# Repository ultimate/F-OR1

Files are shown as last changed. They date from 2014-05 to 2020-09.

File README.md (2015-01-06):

#F-OR1

Bei der *Formula-OR1* (kurz: *F-OR1*) geht es darum das eigene Können in Bezug auf das Fahren und Bauen eines eigenen Modellautos unter beweis zu stellen. Ziel ist es dabei auf Basis einer vereinheitlichten Grundauswahl an Komponenten ein eigenes Fahrzeug zu entwickeln, zu bauen und sicher durch die Rennen zu steuern.

## Alle Infos auf einen Blick

* **[Reglement](Reglement.md)**
  * **[Anhang A](Reglement - Anhang A.md)**
  * **[Anhang B](Reglement - Anhang B.md)**
* **Gesamt-Wertung**
  * **[Ewige Tabelle](Ranking-1.md)**
  * **[Best-of-3](Ranking-2.md)**
* **Challenges**
  * **[2015-01-09](Challenges/2015-01-09.md)**
  * **[2014-09-26](Challenges/2014-09-26.md)**
  * **[2014-07-18](Challenges/2014-07-18.md)**
  * **[2014-03-21](Challenges/2014-03-21.md)**

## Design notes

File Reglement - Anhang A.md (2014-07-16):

#Reglement - Anhang A

Dieser Anhang enthält Daten und Beschreibungen, sowie ggf. Referenzdokumente für die nach dem Reglement festgelegten Fahrzeugkomponenten & -eigenschaften

Referenz: [Zum Hauptdokument](Reglement.md)

##I. Allgemeines
1. Der maximale Gesamtpreis für Zukaufteile darf die Summe von 50 € pro Teilnehmer nicht überschreiten.
2. Die Fertigung von Teilen per 3D-Druck ist so weit wie möglich auf FDM-3D-Drucker zu beschränken. Die Verwendung des „Objet 30 pro“ 3D-Druckers ist nur für Kleinteile zulässig (z. B. Zahnräder)
3. Fast alle vorgegebenen Grundkomponenten wurden im CAD nachmodelliert und stehen unter [Komponenten](Komponenten) als SolidWorks-Teil/Baugruppe oder STEP zur Verfügung.

##II. Mechanik
1. Allgemeines
  1. Die Prüfung der äußeren Abmaße von kleiner 290 x 215 x 87 mm wird durch die *F-OR1-Normbox* („SpacePilot Pro“-Box) vorgenommen.
  2. Das Fahrzeug muss bei geschlossenem Deckel vollständig, gewaltfrei und in genau dem Zustand in die Box passen, in dem es an der Challenge teilnimmt.
2. Freigaben:
  1. Keine Material- oder Fertigungsbeschränkungen (ausgenommen 3D-Druck, siehe oben)
  2. Äußere Modifikation bestimmter Elektronik-Komponenten (s.u.)
3. Verbote:
  1. Keine weiteren Beschränkungen

##III. Motor & Elektronik
1. Allgemeines
  1. Es werden die folgenden Grundkomponenten vorgeschrieben:
<table><tbody><tr><th>Komponente</th><th>Bezeichnung</th><th>Links</th></tr>
<tr><td>Motor</td><td>B20-30-24S-FIN Brushless Inrunner Motor 3860kv</td><td>[Datenblatt](Datenblätter/Brushless Motor B20-30-24S-FIN - Datenblatt.pdf)<br>[Hobbyking](http://hobbyking.com/hobbyking/store/__24930__B20_30_24S_FIN_Brushless_Inrunner_Motor_3860kv.html)</td></tr>
<tr><td>Motorregler</td><td>Hobby King X-Car 60A Brushless Car ESC</td><td>[Datenblatt](Datenblätter/Hobby King X-Car Motorregler - Datenblatt.pdf)<br>[Manual](Datenblätter/Hobby King X-Car Motorregler - User Manual.pdf)<br>[Software](Datenblätter/Hobby King X-Car Motorregler - USB Programming Software.zip)<br>[(Screenshot)](Datenblätter/Hobby King X-Car Motorregler - USB Programming Software.jpg)<br>[Hobbyking](http://hobbyking.com/hobbyking/store/uh_viewItem.asp?idProduct=28375)</td></tr>
<tr><td>~~Motorregler (alt)~~</td><td>~~Turnigy Multistar 10 Amp Multi-rotor Brushless ESC 2-3S~~</td><td>~~[Datenblatt](Datenblätter/Turnigy Motorregler - Datenblatt.pdf)<br>[Manual](Datenblätter/Turnigy Motorregler - Manual.pdf)<br>[Hobbyking](http://hobbyking.com/hobbyking/store/__25362__Turnigy_Multistar_10_Amp_Multi_rotor_Brushless_ESC_2_3S.html)~~</td></tr>
<tr><td>Akku</td><td>Rhino 1050mah 2S 7.4v 20C Lipoly Pack</td><td>[Datenblatt](Datenblätter/Rhino Lipoly Pack 1050 - Datenblatt.pdf)<br>[Hobbyking](http://hobbyking.com/hobbyking/store/__7307__Rhino_1050mah_2S_7_4v_20C_Lipoly_Pack.html)</td></tr>
<tr><td>Lenkservo</td><td>HK15138 Standard Analog Servo 38g / 4.3kg / 0.17s</td><td>[Datenblatt](Datenblätter/Servo HK15138 - Datenblatt.pdf)<br>[Hobbyking](http://hobbyking.com/hobbyking/store/__16269__HK15138_Standard_Analog_Servo_38g_4_3kg_0_17s.html)</td></tr>
</table>
2. Freigaben:
  1. Beliebige Wahl von Kabeln und Steckern
  2. Äußere Modifikation des Servos (Gehäuse), ohne Veränderungen der Funktionalität oder des Bewegungsbereichs
  3. Äußere Modifikation der Fernbedienung (Gehäuse), ohne Veränderungen der Funktionalität
  4. Austausch der AA-Batterien durch einen Lipo-Akku inkl. der dafür erforderlichen Anpassung des Gehäuses und der Anschlusskabel.
  5. Der Lüfter des Motorreglers darf entfernt und/oder für andere Zwecke verwendet werden (z.B. zum Kühlen des Motors). Bei Bedarf darf dafür auch das Kabel verlängert werden.
3. Verbote:
  1. Sämtliche zusätzliche elektronische Komponenten
  2. Sämtliche sonstige Modifikationen der vorgeschriebenen Komponenten (z.B. elektronisch/funktional), die über die oben genannten Freigaben hinausgehen.
  3. Weitere Energiequellen (z. B. Solarzellen, Kondensatoren, Energierückgewinnung, etc.)

##IV. Steuerung & Software
1. Allgemeines
  1. Aus folgenden Grundkomponenten kann gewählt werden:
<table><tbody><tr><th>Komponente</th><th>Bezeichnung</th><th>Links</th></tr>
<tr><td>Pistole</td><td>Hobby King GT-2 2.4Ghz 2Ch Tx & Rx</td><td>[Datenblatt](Datenblätter/Hobby King GT-2 - Datenblatt.pdf)<br>[Manual](Datenblätter/Hobby King GT-2 - Manual.pdf)<br>[Control Panel](Datenblätter/Hobby King GT-2 - Control Panel.jpg)<br>[Hobbyking](http://hobbyking.com/hobbyking/store/__10608__Hobby_King_GT_2_2_4Ghz_2Ch_Tx_Rx.html)</td></tr>
<tr><td>Knüppel</td><td>Hobby King 2.4Ghz 4Ch Tx & Rx V2 (Mode 1)</td><td>[Datenblatt](Datenblätter/Hobby King TR6A - Datenblatt.pdf)<br>[Hobbyking](http://www.hobbyking.com/hobbyking/store/uh_viewItem.asp?idProduct=8337)</td></tr>
</table>
2. Freigaben:
  1. Keine weiteren Freigaben
3. Verbote:
  1. Sämtliche zusätzliche Steuerungs- Software- oder Sensorik-Komponenten
  2. Modifikationen der vorgeschriebenen Komponenten

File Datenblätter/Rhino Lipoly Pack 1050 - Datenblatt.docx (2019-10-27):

# Datenblatt Rhino Lipoly Pack 1050

Bezeichnung | Rhino 1050mah 2S 7.4v 20C Lipoly Pack
Link | http://hobbyking.com/hobbyking/store/__7307__Rhino_1050mah_2S_7_4v_20C_Lipoly_Pack.html

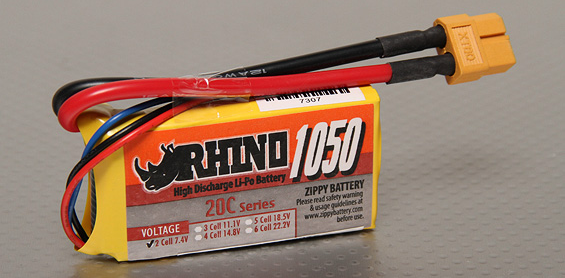
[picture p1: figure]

Bild
Elektrische Eigenschaften | Capacity 1050mAh Constant discharge 20C Burst rate 30C (15sec) Configuration 2S 7.4v Discharge plug XT60 Max Charge Rate 2C

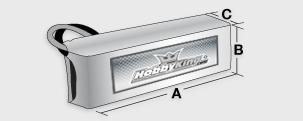
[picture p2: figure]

Mechanische Eigenschaften | Weight (g) 71 Length-A (mm) 70 Height-B (mm) 35 Width-C (mm) 11

F-OR1 Datenblatt Stand: 13.12.2013

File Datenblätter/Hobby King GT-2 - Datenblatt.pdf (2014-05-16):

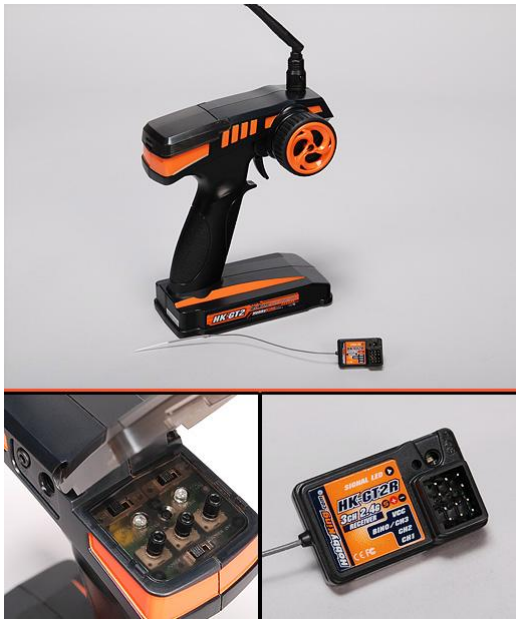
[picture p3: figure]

F-OR1 | Datenblatt | Stand: 13.12.2013

# Datenblatt Hobby King GT-2

Bezeichnung | Hobby King GT-2 2.4Ghz 2Ch Tx & Rx
Link | http://hobbyking.com/hobbyking/store/__10608__Hobby_King_GT_2_2_4Ghz_2Ch_T x_Rx.html (http://hobbyking.com/hobbyking/store/__10608__Hobby_King_GT_2_2_4Ghz_2Ch_Tx_Rx.html)

Bild

Sender | Model | Car/Boat
Channels | 2ch
RF power | Less than 20dbm
Modulation | GFSK
Code type | Digital
Sensitivity | 1024
Low voltage warning | Yes (less than 9V)
DSC port | Yes (3.5mm)
Charge port | Yes
Power | 12VDC (1.5AA x 8)

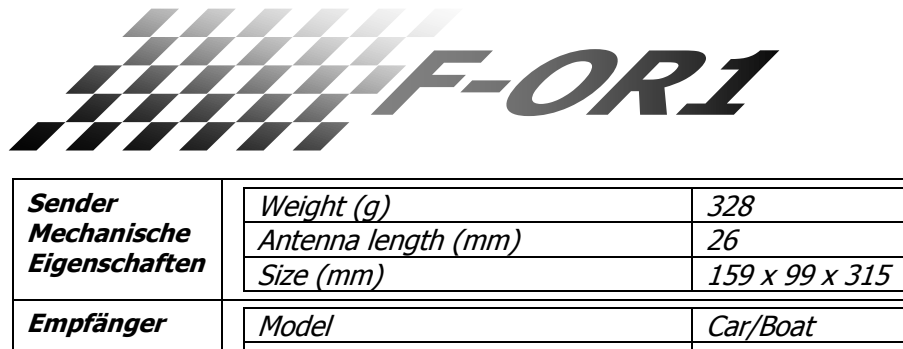
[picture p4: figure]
Sender Mechanische Eigenschaften; Weight (g); Antenna length (mm); Size (mm); Empfänger; Model; Car/Boat

F-OR1 | Datenblatt | Stand: 13.12.2013
Channels | 3ch
Frequency band | 2.4Ghz
Modulation | GFSK
Sensitivity | 1024
RF. receiver sensitivity | -100dbm
Power | 4.5~6VDC

Empfänger
Mechanische
Eigenschaften
Weight (g) | 5
Antenna length (mm) | 26
Size (mm) | 37.6 x 22.3 x 13

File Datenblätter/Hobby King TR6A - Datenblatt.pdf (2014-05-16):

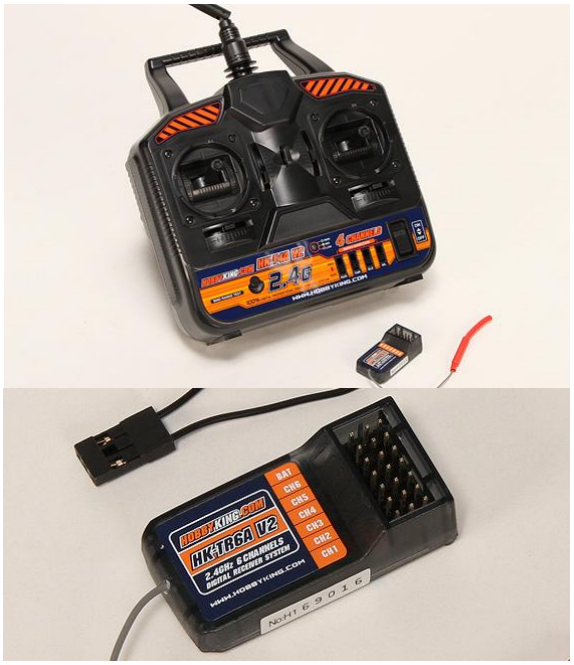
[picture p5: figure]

F-OR1 | Datenblatt | Stand: 13.12.2013

# Datenblatt Hobby King TR6A

Bezeichnung | Hobby King 2.4Ghz 4Ch Tx & Rx V2 (Mode 1)
Link | http://www.hobbyking.com/hobbyking/store/uh_viewItem.asp?idProduct=8337

Bild

Sender

Model | Universal
Mode | 1 (Throttle on the right)
Channels | 4ch
Power | 12VDC (1.5AA x 8) ?

Sender
Mechanische
Eigenschaften
Weight (g) | 989 (Package)
Antenna length (mm) | ?
Size (mm) | ?
Empfänger | Model | Car/Boat
Channels | 6ch
Frequency band | 2.4Ghz
Power | 4.5~6VDC ?

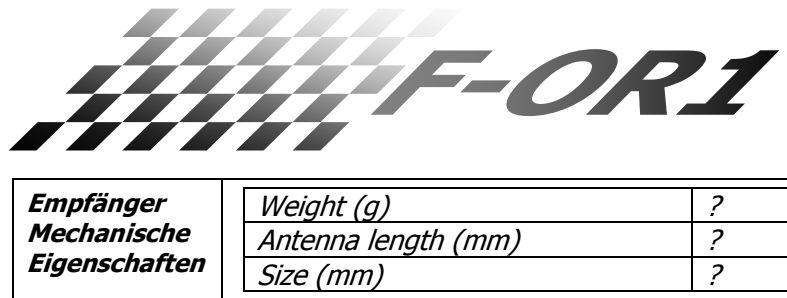
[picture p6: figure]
Empfänger Mechanische Eigenschaften; Weight (g); Antenna length (mm); Size (mm)

F-OR1 | Datenblatt | Stand: 13.12.2013

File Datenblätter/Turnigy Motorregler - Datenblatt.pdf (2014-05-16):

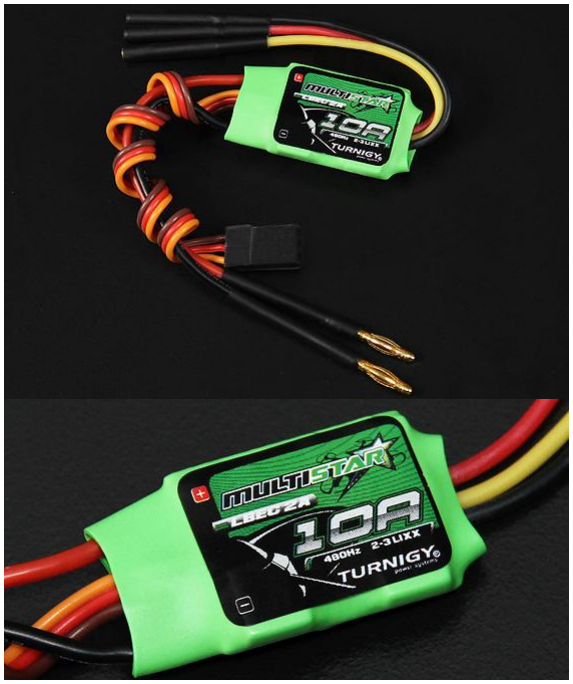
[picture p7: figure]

F-OR1 | Datenblatt | Stand: 13.12.2013

# Datenblatt Turnigy Motorregler

Bezeichnung | Turnigy Multistar 10 Amp Multi-rotor Brushless ESC 2-3S
Link | http://hobbyking.com/hobbyking/store/__25362__Turnigy_Multistar_10_Amp_Multi_ rotor_Brushless_ESC_2_3S.html (http://hobbyking.com/hobbyking/store/__25362__Turnigy_Multistar_10_Amp_Multi_rotor_Brushless_ESC_2_3S.html)

Bild

Elektrische Eigenschaften
Constant Current | 10A
Input Voltage | 2-3 cell Lipoly
BEC | Yes (linear) [Remove middle wire to dissable]
BEC Output | 5V/2A
PWM | 8 KHz
Max RPM | 240,000rpm for 2 Pole Brushless Motor
Discharge Plugs | Male 3.5mm Bullet Connector
Motor Plugs | Female 3.5mm Bullet Connector

Mechanische Eigenschaften
PCB Size (mm x mm) | 22 x 17
Weight (g) | 16

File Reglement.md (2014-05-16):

# Reglement
##I. Organisation
1. Organisation und Leitung der *F-OR1* übernimmt das *F-OR1-Komitee* bestehend aus Marco und Julian.
2. Das *F-OR1-Komitee* behält sich jederzeit Änderungen vor. Änderungen werden mit rechtzeitiger Ankündigung und Wirkung zur übernächsten Challenge bekannt gegeben. Änderungen können mit Einverständnis aller Teilnehmer auch kurzfristig in Kraft gesetzt werden.

##II. Grundlegendes
1. Der Spaßt steht im Vordergrund!
2. Der Zeitaufwand während der Arbeitszeit ist auf einen ange-messenen Zeitrahmen zu begrenzen.
3. Fertigungs- und Material-Kosten sind so gering wie möglich zu halten (siehe auch [Anhang A](Reglement - Anhang A.md)).
4. In diesem Repository werden alle allgemeingültigen Information gesammelt und veröffentlicht. Dazu gehören z. B. das Reglement, Rennergebnisse, Datenblätter, etc.

##III. Durchführung
1. Das Können der Fahrer und der Fahrzeuge wird in regelmäßigen Challenges ermittelt deren Termin unter allen Teilnehmern abgestimmt wird.<br/>Ziel ist es die Challenges ungefähr im Abstand von 2-3 Monaten auszutragen. 
2. Die Challenges werden als **Team-Events an einem Freitag nach der Arbeit im "Labor"** oder an einem anderen verabredeten Ort ausgetragen.
3. Längeren Challenges können alternativ auch als Rennwoche durchgeführt werden. In diesem Fall hat innerhalb der festgelegten Rennwoche jeder Teilnehmer die Möglichkeit die Challenge beliebig oft zu absolvieren um eine Wertung zu erlangen. Absolvieren der Challenge, sowie die Wertung muss dabei von mind. einem anderen Teilnehmer beobachtet und bestätigt werden.
4. Sofern es die Art der Challenge zulässt ist bei Urlaub oder Krankheit ein Ausweichtermin für das Erlangen der Wertung auch außerhalb des Team-Events oder der Rennwoche für den betroffenen Teilnehmer möglich. Die Festlegung des Ersatz-Termins erfolgt in Absprache mit dem *F-OR1-Komitee*. Der Ersatztermin ist möglichst zeitnah zum eigentlichen Termin der Challenge anzusetzen. Nach Möglichkeit sind Urlaube jedoch schon bei der Festlegung des Challenge-Termins zu berücksichtigen.
5. Der Teilnehmer, der bei der aktuellen Challenge am **schlechtesten** abschneidet, legt die Aufgabe/den Inhalt der nächsten Challenge und damit auch die Ausführungsvariante der Challenge fest. Sollte ein Teilnehmer zweimal in Folge die Wahl der nächsten Aufgabe zugesprochen bekommen, so fällt die Festlegung der Aufgabe/des Inhalts der nächsten Challenge auf den nächstbesseren Teilnehmer.<br/>Vorschläge für mögliche Challenges können [Anhang B](Reglement - Anhang B.md) entnommen werden.
6. Testfahrten können auch jederzeit auch außerhalb des Team-Events bzw. der Rennwoche beliebig oft durchgeführt werden, werden jedoch nicht in die Wertung genommen.
7. Die Festlegung des Termins und der Art der nächsten Challenge hat möglichst zeitnah nach Abschluss der aktuellen Challenge zu erfolgen und ist jedoch **mind. 14 Tage im Voraus** anzukündigen.
8. Für jede Challenge ist ein **eindeutiges, messbares Wertungskriterium** festzulegen, welches zusammen mit der Festlegung der Art der Challenge bekannt gegeben wird.<br/>Bei der Wahl einer mehrstufigen Wertung (siehe [Anhang B](Reglement - Anhang B.md)) ist darüber hinaus ein entsprechender Zeit- oder Ablaufplan zu veröffentlichen.
9. Hinzukommende oder ausscheidende Teilnehmer müssen ihr hinzukommen bzw. ausscheiden bis spätestens 14 Tage vor der nächsten Challenge bekannt geben.

##IV. Teilnahmebestimmungen
1. Teilnehmen kann jeder, der mit seinem Fahrzeug die nachfolgenden Bestimmungen einhält.
2. Für die Beschreibung der Fahrzeuge werden die **Eigenschaften nach 3 Kategorien** unterschieden:
    1. **Mechanik** - Beinhaltet die tragende Konstruktion wie z. B. Fahrgestell und Karosserie sowie Aufhängung, Räder, Antriebs- und Lenkmechnik und Verbindungselemente
    2. **Motor & Elektronik** – Beinhaltet den Motor, sowie sämtliche elektronischen Bauteile die für die elektrische Versorgung des Fahrzeugs oder den Betriebs des Motors erforderlich sind (ausgenommen Steuerungskompo-nenten, siehe c.), sowie Kabel und Stecker
    3. **Steuerung & Software** – Beinhaltet sämtliche Komponenten, die für die Steuerung des Fahrzeugs erforderlich sind, inkl. ggf. dazugehöriger Sen-sorik (einschließlich Fernsteuerung etc.)
Bei nicht eindeutiger Zuordbarkeit der Komponenten zu einer Kategorie entscheidet das *F-OR1-Komitee* über die Zuordnung.
3. Für alle Fahrzeuge wird die in [Anhang A](Reglement - Anhang A.md) beschriebene Grundkonfiguration an festgelegten Komponenten & Eigenschaften vorgeschrieben. Alle Komponenten sind im unmodifizierten Originalzustand zu verwenden. Veränderungen oder Manipulationen der Komponenten sind nur nach vorheriger Freigabe durch das Reglement zulässig.
4. Nach Abschluss einer Challenge, dürfen bis zum Abschluss der nächsten Challenge dürfen ausschließlich Modifikationen innerhalb **einer Kategorie** vorgenommen werden.<br/>Der Stand des Fahrzeugs wird für jede Challenge fotografisch sowie falls erforderlich anderweitig dokumentiert (z. B. Schalt-plan, Code, etc., siehe nachfolgend Fahrzeugeigenschaften)
5. Das Wechseln und/oder Nachladen des Akkus ist innerhalb einer Wertung (siehe V) nicht gestattet. Eine Ausnahme stellen mehrstufige Challenges dar, sofern das Wechseln und/oder Nachladen im Ablauf beschrieben ist.

##V. Challenge-Wertung
1. Die Wertung der Challenges erfolgt durch Punktvergabe anhand des zuvor festgelegten Wertungskriteriums in der folgenden Punktefolge und wird an die tatsächliche Teilnehmerzahl n der Challenge angepasst:<br><table><tbody><tr><th>Platz</th><th>1</th><th>2</th><th>3</th><th>...</th><th>n-2</th><th>n-1</th><th>n</th></tr><tr><td>Punkte</td><td>n-1</td><td>n-3</td><td>n-4</td><td>...</td><td>1</td><td>0</td><td>0</td></tr></table><br>Bei Wertungsgleichheit mehrerer Teilnehmer m erhalten diese die gleiche Punktzahl entsprechend des besseren Platzes. Die nachfolgenden m-1 Plätze werden ausgesetzt.
2. Über die Punktwertung hinaus werden Bonus- oder Strafpunkte wie folgt vergeben bzw. abgezogen:<br><table><tbody><tr><th>Kriterium</th><th>Punkte</th></tr><tr><td>Nicht-Teilnahme an der Challenge</td><td>- 2</td></tr><tr><td>Keine Modifikation des Fahrzeugs seit der letzten Challenge</td><td>+ 2</td></tr><tr><td>Design-Bonus</td><td>+ 1</td></tr></table><br>Anmerkungen:
    1. Die Nicht-Teilnahme an der Challenge bedeutet den Ausschluss bei der Vergabe der Bonus-Punkte.
    2. Sofern die Art der Challenge eine Urlaubs oder Krankheitsregelung nach II/4 nicht zulässt, werden keine Strafpunkte für die Nicht-Teilnahme abgezogen.
    3. Der Design-Bonus wird durch demokratische Wahl der Teilnehmer vergeben und belohnt das optisch ansprechendste Fahrzeug. Er wird bei jeder Challenge neu vergeben.

##VI. Gesamt-Wertung
1. Die Ergebnisse der Team-Events bzw. Rennwochen in Form der Challenge-Wertung fließen in die Gesamtwertung ein.
2. Die Gesamtwertung ist untergliedert in mehrere Rankings:
    1. **Ewige-Tabelle**<br>Die **Punktzahlen aller Challenge-Wertungen** inkl. Bonus-/Strafpunkte werden je Teilnehmer addiert. Bei Punktgleichheit führt der Spieler, der ohne Berücksichtigung von Bonus-/Strafpunkten mehr Punkte hat.
    2. **Best-of-3**<br>Die **Punktzahlen der letzten 3 Challenge-Wertungen** exkl. Bonus-/Strafpunkte werden je Teilnehmer addiert.
3. Die Rankings werden von Julian gepflegt und hier auf github veröffentlicht:
    1. **[Ewige-Tabelle](Ranking-1.md)**
    2. **[Best-of-3](Ranking-2.md)**

##VII. Anhänge
* **[Anhang A](Reglement - Anhang A.md)** (Technische Vorgaben)
* **[Anhang B](Reglement - Anhang B.md)** (Challenge-Vorschläge)

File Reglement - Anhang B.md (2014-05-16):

#Reglement - Anhang B

Dieser Anhang enthält Vorschläge und Kurzbeschreibungen möglicher Challenges.

Referenz: [Zum Hauptdokument](Reglement.md)

##I. Vorschläge für mögliche einstufige Challenges
1.	Beste Rundenzeit(en) (Wertung über 1-n beste Runden)
2.	Topspeed oder Topbeschleunigung
3.	Kleinste Zeit für X Runden
4.	Meistgefahrene Runden pro Zeit
5.	Ausdauer (Meiste Runden mit 1 Akkuladung, Durchführung auf sehr einfacher Strecke wie „Oval“ oder „Acht“)
6.	Geschicklichkeitsübung (Hindernissparcour, Slalom, Weit-sprung, …)
7.	Fahrzeug-Fahrer-Kombi-Spring (Fahrer & Fahrzeug müssen Strecke gleichzeitig absolvieren)
8.	Dragster
9.	Fußball
10.	Crash-Derby

##II.	Vorschläge für mögliche mehrstufige Challenges
1.	K.O.-Meisterschaft (bestehend aus einer der obigen Challenges)
2.	Gruppen-Rennen
3.	Jeder-Gegen-Jeden (Mini-Liga)

##III. Richtwerte für die Auswahl der Challenges
1.	Eine Wertung muss mit 1 Akkuladung erzielt werden können.

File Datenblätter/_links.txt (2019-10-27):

http://www.hobbyking.com/hobbyking/store/RC_PRODUCT_SEARCH.asp?strSearch=bone
http://www.hobbyking.com/hobbyking/store/__49322__S3M_153_Belt_The_Devil_1_10_4WD_Drift_Car.html
http://www.hobbyking.com/hobbyking/store/__49321__S3M_174_Belt_The_Devil_1_10_4WD_Drift_Car.html
http://www.hobbyking.com/hobbyking/store/__52069__RJX_X_treme_50_EP_Aluminum_Front_Belt_Pulley_S3M_16T_XT90_60007.html
http://www.hobbyking.com/hobbyking/store/__52099__RJX_X_TRON_500_Tail_Belt_Pulley_16T_with_Pin.html
http://www.hobbyking.com/hobbyking/store/__41357__Alu_15T_Pulley_1_10_Hobbyking_Mission_D_4WD.html
http://www.hobbyking.com/hobbyking/store/RC_PRODUCT_SEARCH.asp?strSearch=pulley
http://www.hobbyking.com/hobbyking/store/__36452__Ball_Diff_Set_1_10_Hobbyking_Mission_D_4WD_GTR_Drift_Car.html
http://www.kugellager-express.de/Kugellager/Miniatur-Kugellager/Miniatur-Kugellager-6--/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

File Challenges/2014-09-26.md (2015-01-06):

#Challenge 2014-09-26

##Beschreibung

Challenge festgelegt durch: **Julian**

###Vorwort
Ihr seid sicher alle gespannt, was ich mir für die nächste Challenge ausdenke – aber es muss noch ein paar Tage in meinem Kopf reifen...
Nur so viel sei schon mal verraten: Sie soll draußen stattfinden! Damit das auch mit dem Wetter noch was wird, der Abstand zur letzten Challenge aber weder zu klein noch zu groß wird, dachte ich wir streben so Ende September an...<br>

Nun zur Challenge an sich: (Sorry, dass es so lang geworden ist... :-/ )

###Ort / Strecke:
* ich schlage vor, dass wir die Challenge [hier (grüner Pfeil)](https://maps.google.de/maps?q=52.524479,13.318796) stattfinden lassen.
* Genau dort wo der Pfeil ist, ist eine kleine Anhöhe, von der man die gesamte Strecke gut im Blick hat (siehe rechts; sollten die Büsche an der West-Ecke stören, können wir die Strecke auch über die Wiese führen – vorausgesetzt dort befinden sich keine Tretminen...)
* da wir damit abseits des Labors sind, sind natürlich auch nicht-h2o-Gäste herzlich eingeladen...

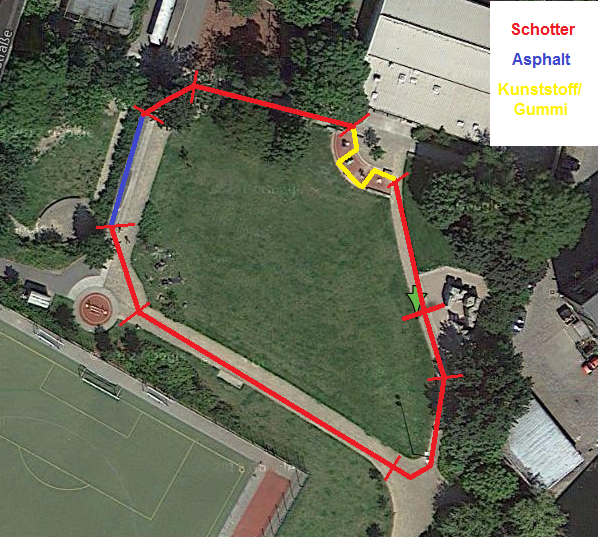
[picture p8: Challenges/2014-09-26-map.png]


*Anmerkung*
* sollte das mit dem Schotter der totale Reinfall sein, so verlegen wir die Challenge auf das Dach des Labors, wo wir einen ähnlichen Streckenverlauf absperren...

###Rennen (ohne Festlegung der Reihenfolge)
1. KO-Rennen (mit Betonung auf "Rennen"; zum Warm werden ;-) ):
  * 1 Runde auf Zeit, alle einzeln nacheinander
  * Auto & Fahrer müssen die Strecke gemeinsam passieren (gelbe Schikane für Fahrer ausgenommen)
  * Start von Auto & Fahrer gleichzeitig, Zeit wird gestoppt, wenn beide (Auto & Fahrer) Ziellinie passiert haben
  * optional: jeder hat 3 Versuche, der beste Versuch zählt – ob die 3 Versuche wahrgenommen werden, kann jeder für sich entscheiden...
  * die Fahrt-Richtung kann (je Versuch) frei gewählt werden
2. KO-Rennen (mit Betonung auf "KO")
  * 5 Runden alle zusammen
  * ab da scheidet jede Runde der letzte aus (also bei 5 Teilnehmern am Ende der 5., 6., 7., 8. Runde; bei 6 entsprechend mehr)
3. Normales Rennen
  * 8 Runden ganz normale, alle zusammen
4. wie 2, nur anders herum
5. wie 3, nur anders herum

###Punktevergabe:
-	Für die Ermittlung des Challenge-Siegers gilt für alle Rennen die gleiche Punktverteilung (Teilnehmerzahl n):<br>
                1. Platz: n-1 Punkte<br>
                2. Platz: n-3 Punkte<br>
                3. Platz: n-4 Punkte<br>
                n-1. Platz: 0 Punkte<br>
                n. Platz: 0 Punkte<br>
                Nicht-Erreichen des Ziels: -1 Punkte (gilt nicht für Rennen 2 & 4 & Mehrfachversuche bei Rennen 1)

###Sonderregeln:
* Während aller Rennen ist das Anfassen der Autos nicht verboten – ist aber an folgende Bedingungen geknüpft:
  * Die Strecke ist in 8 Abschnitte geteilt (siehe Karte: 3 Geraden, 3 Kurven, 1 Schikane, 1 Bodenwell)
  * Das Auto muss nach dem Anfassen an den Anfang des Abschnitts zurückversetzt 
  * Ich glaub das ist Strafe genug, wenn man bedenkt, dass man dafür ohnehin ganz schön wetzen muss...
* In Ermangelung einer Steckdose ist natürlich das Nachladen (und auch Tauschen) des Akkus verboten.
* Im Reparaturfall benötigtes Werkzeug/Ersatzteile ist natürlich mitzubringen...

##Wertung & Teilnehmer

Teilnehmer    | 1 (Zeit)                           | 1 (Pkt.) | 2 (Pl.) | 2 (Pkt.) | 3 (Pl.) | 3 (Pkt.) | 4 (Pl.) | 4 (Pkt.) | 5 (Pl.) | 5 (Pkt.) | Ges. (Pl.) | Ges. (Pkt.) | Punkte | Boni  
------------- | ---------------------------------- | -------- | ------- | -------- | ------- | -------- | ------- | -------- | ------- | -------- | ---------- | ----------- | ------ | ------     
**Jonas**     | 30.4 s<br>21.6 s<br>**21.1 s**     | 2        | 2       | 2        | 3       | 1        | 1       | 4        | 1       | 4        | 1          | 13          | 4      |   
**Marco**     | **24.7 s**<br>ausgesetzt<br>27.1 s | 1        | 1       | 4        | 1       | 4        | 2       | 2        | 2       | 2        | 2          | 13          | 2      |            
**Chang-Hae** | 25.3 s<br>23.2 s<br>**21.0 s**     | 4        | 4       | 0        | 2       | 2        | 3       | 1        | 3       | 1        | 3          | 8           | 1      | + 1 (keine Modifikation)
**Martin**    | 38.6 s<br>ausgesetzt<br>**31.4 s** | 0        | 3       | 1        | -       | -1       | -       | -        | -       | -1       | 4          | -1          | 0      |        
**Julian**    | 44.7 s<br>**39.3 s**<br>42.1 s     | 0        | 5       | 0        | -       | -1       | 4       | 0        | -       | -1       | 5          | -2          | 0      | + 1 (Design)               

##Rückblick
* Streckenänderung
  * Da es dann doch etwas nass war für die Schotterstrecke haben wir uns dafür entschlossen das Rennen doch wieder auf dem Hof stattfinden zu lassen. Der Streckenverlauf und Rennen wurde dabei aber beibehalten.
* Rennen 1
  * Das KO-**Rennen** war so spaßig wie erwartet. Sowohl für die rennenden, als auch für die Zuschauer :-)
  * Die Startreihenfolge wurde entsprechend der Platzierung des ersten Rennens gewählt. Also: Marco, Chang-Hae, Martin, Jonas, Julian
  * Jonas Wagen verliert in der Schikane ein Vorderrad. Das hindert es aber nicht daran trotzdem ins Ziel zukommen.
  * Marco traut sich nach seinem ersten guten Lauf sogar eine Runde auszusetzen.
  * Martins Wagen verliert im ersten Versuch "nur" den Spoiler. Den zweiten Versuch muss er aber abbrechen, weil er ein Hinterrad verliert...
  * Am Ende entscheidet nur 1/10 Sekunde zwischen Chang-Hae und Jonas
* Rennen 2
  * Marco entscheidet das Rennen knapp für sich...
* Rennen 3
  * Julians Akku ist bereits nach 2 Rennen durch und das Auto kommt nicht mehr von der Stelle, daher muss er für dieses Rennen aufgeben.
  * Bei Martin zerlegt es die gedruckten Teile im Getriebe, womit er leider für alle weiteren Rennen ausfällt...
* Rennen 4
  * Nach einem Akku-Wechsel ist Julian wieder dabei. Das ändert aber nichts daran, dass er Probleme hat mit dem Geradeausfahren...
  * Zudem bricht bei Julian die Motorwelle. Da war die Spannung durch den Riemen wohl etwas groß. Damit ist auch für ihn für heute Schluss...
  * Diesmal lässt Jonas Marco knapp hinter sich.
* Rennen 5
  * Mit drei verbliebenen Fahrern geht es ins dritte Rennen.
  * Die Ausgangssituation ist denkbar spannend. Fast alles ist noch möglich
* Stechen
  * Nach dem 5. Rennen sind Marco und Jonas gleich auf. Der Sieger wird durch ein Stechen ermittelt.
  * Dabei müssen beide gleichzeitig mit ihrem Fahrzeug mitrennen.
* Allgemeines
  * Chang-Hae kassiert als Erster den Bonus-Punkt für das Nicht-Modifizieren seines Fahrzeugs seit der letzten Challenge.
  * Der Design-Punkt ging wieder knapp an Julian. Abgestimmt haben dabei auch 4 Zuschauer.

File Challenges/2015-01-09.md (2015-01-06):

#Challenge 2015-01-09

##Beschreibung

Challenge festgelegt durch: **Martin**

###Zum Rennen selbst
Würde es gerne draußen auf dem Platz vor dem Labor stattfinden lasen, die Strecke wieder kurz vorher hergerichtet. Das hatte ja gut funktioniert beim letzten Mal.
Gerade zu dem Datum könnte das Wettertechnisch so ziemlich alles sein. Und genau darum geht es. 
**Ob Regen oder Schnee wir fahren draußen.**

###Zu den Rennen selbst:
1. Normales Rennen 6 runden wer Erster ist, ist halt erster nichts Besonderes.
2. Nun sollten alle die Strecke kennen, also jetzt dann ein kleines Zeitrennen, gefahren werden nacheinander 3 Runden am Stück. Sind also 2 fliegende runden. Startreihenfolge wird nach der Platzierung aus 1. ermittelt  
3. Gefahren wird in beide Richtungen. Diejenigen die vorher eine ungerade Platzierung hatten  fahren diesmal in die andere die anderen behalten ihre Richtung bei. (6 Runden)
4. Wie drittens aber andersrum damit sich keiner beschwert.
5. Als letztes noch etwas damit wir auch was zum reparieren bekommen, Nach dem heiländer Motto es kann nur einen geben. Jeder klebt sich einen Luftballon auf das Dach und befestigt einen stabilen Draht Vorne am Auto. Jetzt wird solange gefahren bis nur noch einer einen ganzen aufgeblasenen Ballon auf dem Dach hat. Es gibt keine Strecke, gefahren werden kann auf dem gesamten Platz. Um die Luftballons werde ich mich kümmern. Ich denke um den Draht kann sich jeder selbst kümmern.

###Punktevergabe
Bei der Punktevergabe bediene ich mich einfach mal bei unserer letzten Challenge.
- Für die Ermittlung des Challenge-Siegers gilt für alle Rennen die gleiche Punktverteilung (Teilnehmerzahl n):<br>
                1. Platz: n-1 Punkte<br>
                2. Platz: n-3 Punkte<br>
                3. Platz: n-4 Punkte<br>
                n-1. Platz: 0 Punkte<br>
                n. Platz: 0 Punkte<br>
                Nicht-Erreichen des Ziels: -1 Punkte (gilt nicht für Rennen 2 & 4 & Mehrfachversuche bei Rennen 1)
- Ausgenommen 5. Es gibt keinen zweiten nur einen ersten und einen Haufen Verlierer. So kann es halt auch nur einen geben der punkte bekommt und zwar 2 an der Zahl. 

###Zu den Luftballons
Julian: Gibt es eine Regel auf welcher Höhe der Ballon sein muss? Gibt es Regeln für den "Draht"?<br>
Martin: Ich hätte gedacht das der Ballon direkt aufs Auto geklebt wird (doppelseitiges Klebeband oder so) und die Autos sind zwar nicht gleich aber doch gleich genug denke ich.  Und zum Draht würde ich zumindest die Wahl was für einen man nimmt freistellen so von wegen Überlegungen zu Steifigkeit gegen Gewicht oder so. und die Höhe der dratspitze würde ich sagen sollten zwischen 130 und 170 mm über Boden passen. 

##Wertung & Teilnehmer

Teilnehmer    | 1 (Pl.) | 1 (Pkt.) | 2 (Zeit) | 2 (Pkt.) | 3 (Pl.) | 3 (Pkt.) | 4 (Pl.) | 4 (Pkt.) | 5 (Zerst. durch) | 5 (Pkt.) | Ges. (Pl.) | Ges. (Pkt.) | Punkte | Boni  
------------- | ------- | -------- | -------- | -------- | ------- | -------- | ------- | -------- | ---------------- | -------- | ---------- | ----------- | ------ | ------
**Marco**     |         |          |          |          |         |          |         |          |                  |          |            |             |        |            
**Chang-Hae** |         |          |          |          |         |          |         |          |                  |          |            |             |        |        
**Martin**    |         |          |          |          |         |          |         |          |                  |          |            |             |        |        
**Jonas**     |         |          |          |          |         |          |         |          |                  |          |            |             |        |        
**Julian**    |         |          |          |          |         |          |         |          |                  |          |            |             |        |            

##Rückblick
* kommt noch

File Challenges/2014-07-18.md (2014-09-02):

#Challenge 2014-07-18

##Beschreibung

Challenge festgelegt durch: **Chang-Hae**<br>
Nachdem die Autos beim letzten Rennen alle reihenweise ausgefallen sind, soll das Thema der nächsten For1 Ausfallsicherheit sein:<br>
Es werden 4 Rennen nach folgendem Ablauf gefahren:

* Erstes Rennen besteht aus 3 Runden in der Halle<br>(1.Platz: 3 Punkte, 2.Platz: 2 Punkte, 3.Platz 1 Punkt, n-ter Platz 0 Punkte, Ziel nicht erreicht/nicht angetreten -3Punkte)
 * 10min Pause
* Zweites Rennen besteht aus 4 Runden in der Halle<br>(1.Platz: 4 Punkte, 2.Platz: 3 Punkte, 3.Platz 2 Punkte, n-ter Platz 0 Punkte, Ziel nicht erreicht/nicht angetreten -4Punkte)
 * 10min Pause
* Drittes Rennen besteht aus 5 Runden in der Halle<br>(1.Platz: 5 Punkte, 2.Platz: 4 Punkte, 3.Platz 3 Punkte, n-ter Platz 0 Punkte, Ziel nicht erreicht/nicht angetreten -5Punkte)
 * 10min Pause
* Viertes Rennen: Wer schafft die meisten Runden (Akku von den Vorrunden darf nicht gewechselt/nachgeladen werden)<br>(1.Platz: 6 Punkte, 2.Platz: 5 Punkte, 3.Platz 4 Punkte)

Die Autos dürfen während der Rennen nicht berührt/repariert werden (müssen also ein Rennen lang halten). Lediglich in den 10min Pausen dürfen die Autos repariert/nachjustiert werden.

##Wertung & Teilnehmer

Teilnehmer    | 1 (Pl.) | 1 (Pkt.) | 2 (Pl.) | 2 (Pkt.) | 3 (Pl.) | 3 (Pkt.) | 4 (Rd.) | 4 (Pkt.) | Ges. (Pl.) | Ges. (Pkt.) | Punkte | Boni  
------------- | ------- | -------- | ------- | -------- | ------- | -------- | ------- | -------- | ---------- | ----------- | ------ | ------
**Marco**     | 1.      | 3        | 1.      | 4        | 1.      | 5        | 6       | 0        | 1.         | 12          | 4      |        
**Chang-Hae** | 2.      | 2        | 2.      | 3        | 4.      | 0        | X+7     | 6        | 2.         | 11          | 2      |         
**Martin**    | 3.      | 1        | 4.      | 0        | 2.      | 4        | X+6     | 5        | 3.         | 10          | 1      |        
**Jonas**     | 4.      | 0        | 3.      | 2        | 3.      | 3        | X+5     | 4        | 4.         | 9           | 0      |        
**Julian**    | -       | -3       | 5.      | 0        | -       | -5       | -       | 0        | 5.         | -8          | 0      | + 1 (Design)      

##Rückblick
* Rennen 1
  * Bei Julian hat's mal wieder das Getriebe zerlegt. Glücklicherweise hatte er ein (gebrauchtes) Ersatzzahnrad, so dass er den Rest des Rennens und die Pause damit verbrachte dieses auszutauschen
* Rennen 2
  * Julian startet verspätet. Das Austauschen des Zahnrads dauerte 2 Minuten länger... Immerhin schafft er es dann ins Ziel.
* Rennen 3
  * Julians Getriebe ist wieder hin. Damit war's das für ihn für diese Challenge...
  * Es bleibt richtig spannend für das 4. Rennen! Chang, Jonas und Martin sind Punktgleich mit 5 Punkten. Nur Marco hat sich mit 12 Punkten abgesetzt. Da es im 4. Rennen keinen Abzug gibt, ist ihm der Sieg der Challenge damit schon sicher...
* Rennen 4
  * In Runde 7 blockiert Marcos Lenkung und er scheidet aus.
  * Chang, Jonas und Martin verzählen sich bei über 20 Runden. Da nur noch der Rundenabstand bekannt ist beginnen wir neu zu zählen (daher X+ in der Tabelle).
  * Jonas muss nach X+5 Runden aufgeben. Bei einem Crash wird sein An-/Aus-Schalter getroffen. Der Schalter bricht ab und bleibt im Zustand "aus" stehen. Das ist wirklich Pech!
  * Martins Akku ist nach X+6 Runden leer. Damit ist er der einzige, der seinen Akku wirklich leer gefahren hat.
  * Chang gewinnt
* Im Anschluss
  * ... drehen alle (bis auf Julian) noch draußen ihre Runden und sind sich einig, dass das viel cooler ist als auf dem rutschigen Hallenboden...
* Allgemeines
  * Birgit war dabei und hat (fast) alles auf Video festgehalten...
  * Der Design-Punkt geht erneut an Julian (immerhin ein kleiner Trostpreis)

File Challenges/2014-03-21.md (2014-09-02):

#Challenge 2014-03-21

##Beschreibung
Challenge festgelegt durch: **Apsrache aller Teilnehmer**<br>
* 2 Serien à 3 Rennen
* Jedes Rennen à 3 Runden
 
##Wertung & Teilnehmer

Teilnehmer    | 1.1 | 1.2 | 1.3 | Serie 1 | 2.1 | 2.2 | 2.3 | Serie 2 | Gesamt  | Punkte | Boni
------------- | --- | --- | --- | ------- | --- | --- | --- | ------- | ------- | ------ | ----
**Chang-Hae** | 2.  | 1.  | 1.  | **1.**  | 1.  | 2.  | 2.  | **1.**  | **1.**  | 2      | 
**Marco**     | 1.  | 2.  | 3.  | **2.**  | 2.  | 3.  | 1.  | **2.**  | **2.**  | 0      |
**Julian**    | 3.  | 3.  | 2.  | **3.**  | 3.  | 1.  | 3.  | **3.**  | **3.**  | 0      | + 1 (Design)

##Rückblick
* Kein einziges Auto ist heil geblieben
* Während der Rennen musten nicht nur die Autos flitzen ;-)
* Der Sprint in die Werkstatt oder zum gedrehten/gecrashten Auto gehörte quasi mit dazu
* Die Motorregler haben wahre Probleme verursacht. Anfahren war Glücksache...
* Leon und Ronald haben sich als Zuschauer köstlich amüsiert :-)

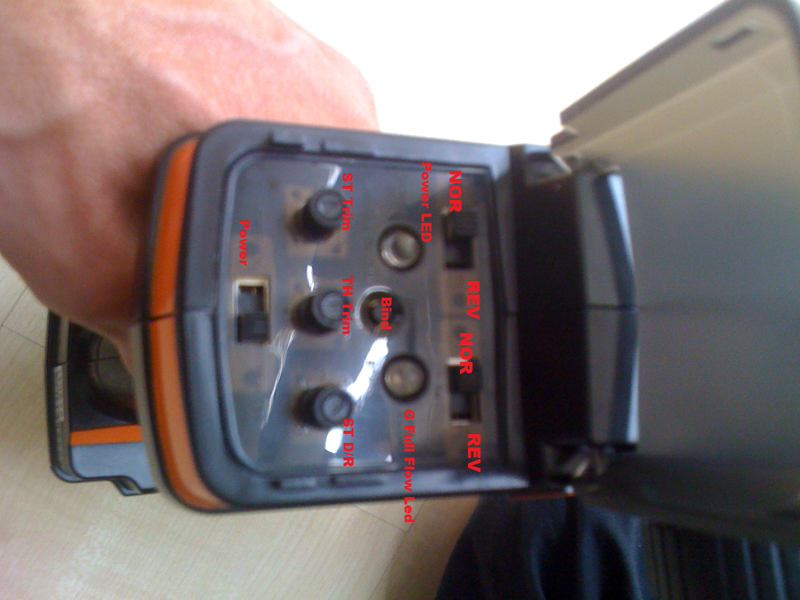
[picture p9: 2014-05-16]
Datenblätter/Hobby King GT-2 - Control Panel.jpg

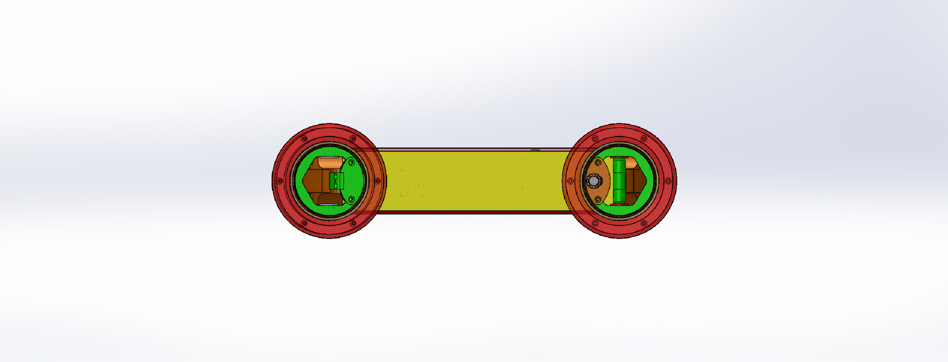
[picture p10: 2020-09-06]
Teilnehmer/ultimate/V3 - 4Wheeler/Export/View-Side.JPG

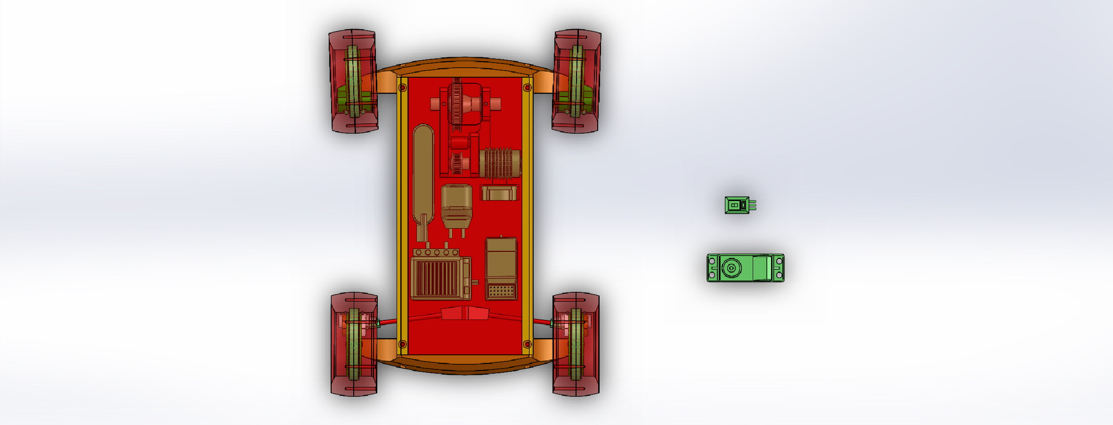
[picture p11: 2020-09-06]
Teilnehmer/ultimate/V3 - 4Wheeler/Export/View-Top.JPG

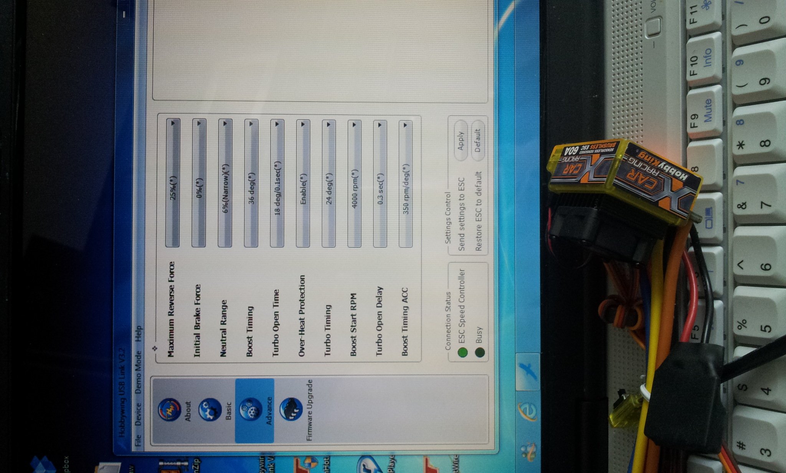
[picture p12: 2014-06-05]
Datenblätter/Hobby King X-Car Motorregler - USB Programming Software.jpg

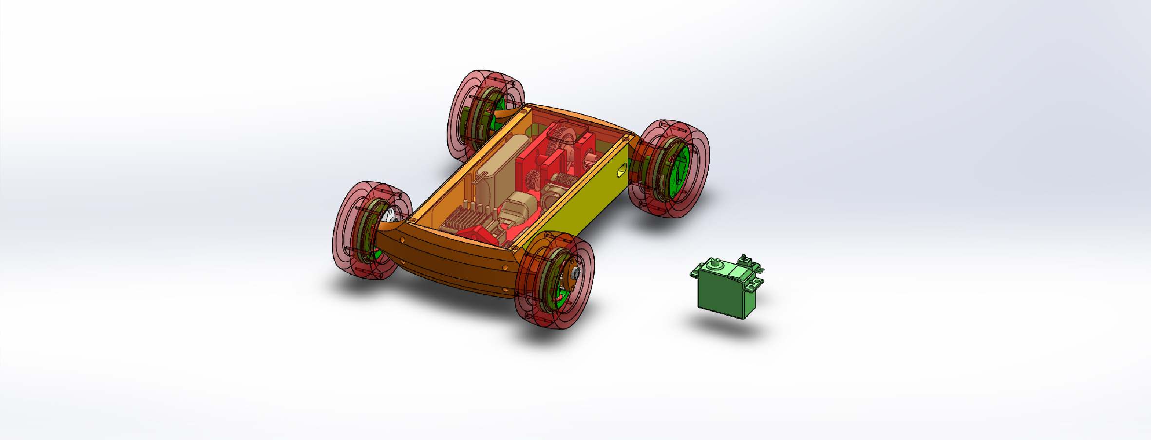
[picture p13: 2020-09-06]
Teilnehmer/ultimate/V3 - 4Wheeler/Export/View-Iso.JPG

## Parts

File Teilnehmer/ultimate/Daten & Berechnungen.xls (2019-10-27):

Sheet: Lenkung
Lenkwinkel gelenkter Räder
Vorgaben |  |  |  |  |  |  |  |  | 29.11.2005
 |  |  |  |  |  |  |  |  | © Hans-Gerd Finke
Achsabstand zwischen Vorder- und Hinterachse L: |  |  |  | 189.500
Abstand der Drehpunkte der gelenkten Vorderräder B: |  |  |  | 160.000
Abstand des Trapezpunktes nach hinten: |  |  |  | 14.000
Abstand des Trapezpunktes nach innen: |  |  |  | 8.500
Trapezwinkel Phi T in Grad: |  |  |  | 32.68857569 |  |  | Zwischenrechnungen |  |  |  | Abweichung
Länge der Spurstangenhebel r: |  |  |  | 16.378 |  |  |  |  |  |  | zwischen
 |  |  |  |  |  |  | u = | -45315.357 |  |  | theoretischen
 |  |  |  |  |  |  | v = | -25331.750 |  |  | und
Errechnet |  |  |  |  |  |  |  |  |  |  | realisierbaren
 |  |  |  |  |  |  | p und q sind die Koeffizienten der zu lösenden quadratischen Gleichung |  |  |  | Phi i in %
Länge der Spurstange l: |  |  |  | 142.309
 |  |  |  |  |  |  |  |  |  |  | -0.000213999685
 |  |  |  |  |  |  |  |  |  |  | -1.081
Theoretischer Zusammenhang der Lenkwinkel |  |  |  |  |  |  |  |  |  |  | -1.863
 |  |  |  |  |  |  |  |  |  |  | -1.529
Lenkwinkel d. |  |  | Lenkwinkel d. | Winkel- |  |  |  |  |  |  | 2.014
äußeren |  |  | inneren | differenz |  |  |  |  |  |  | 26.096
Rades in Grad |  |  | Rades in Grad | in Grad |  |  |  |  |  |  | #NUM!
 |  |  |  |  |  |  |  |  |  |  | #NUM!
Phi a | cot (Phi a) | cot (Phi i) | Phi i | Delta Phi Soll |  |  |  |  |  |  | #NUM!
 |  |  |  |  |  |  |  |  |  |  | #NUM!
0.001 | 57295.780 | 57294.935 | 0.001 | 1.473650636e-08
5.000 | 11.430 | 10.586 | 5.397 | 0.397
10.000 | 5.671 | 4.827 | 11.704 | 1.704
15.000 | 3.732 | 2.888 | 19.101 | 4.101
20.000 | 2.747 | 1.903 | 27.719 | 7.719
25.000 | 2.145 | 1.300 | 37.565 | 12.565
30.000 | 1.732 | 0.888 | 48.404 | 18.404
35.000 | 1.428 | 0.584 | 59.723 | 24.723
40.000 | 1.192 | 0.347 | 70.841 | 30.841
45.000 | 1.000 | 0.156 | 81.152 | 36.152
Berechnung der mit dem Lenktrapez realisierbaren Lenkwinkel
Lenkwinkel d. | Winkel des | Koordinaten | Koordinaten |  |  | Koordinaten | Koordinaten | Winkel des | Lenkwinkel d. | Winkel-
äußeren | äußeren Spur- | des äußeren | des äußeren |  |  | des inneren | des inneren | inneren Spur- | inneren | differenz
Rades in Grad | stangenhebels | Kreisbogens | Kreisbogens |  |  | Kreisbogens | Kreisbogens | stangenhebels | Rades in Grad | in Grad
Phi a | Phi Sa | xa | ya | -p | q | xi | yi | Phi Si | Phi i | Delta Phi Ist
0.001 | 32.688 | 8.845 | 13.784 | 299.961 | 22492.790 | 151.154 | 13.784 | 32.690 | 0.001 | 1.259647797e-08
5.000 | 27.689 | 7.610 | 14.503 | 297.568 | 22135.472 | 149.910 | 12.902 | 38.027 | 5.338 | 0.338
10.000 | 22.689 | 6.317 | 15.111 | 295.104 | 21770.544 | 148.587 | 11.747 | 44.175 | 11.486 | 1.486
15.000 | 17.689 | 4.976 | 15.604 | 292.590 | 21401.501 | 147.183 | 10.196 | 51.497 | 18.809 | 3.809
20.000 | 12.689 | 3.598 | 15.978 | 290.048 | 21031.554 | 145.680 | 7.949 | 60.966 | 28.278 | 8.278
25.000 | 7.689 | 2.191 | 16.231 | 287.497 | 20663.681 | 143.868 | 2.828 | 80.056 | 47.368 | 22.368
30.000 | 2.689 | 0.768 | 16.360 | 284.957 | 20300.618 | #NUM! | #NUM! | #NUM! | #NUM! | #NUM!
35.000 | -2.311 | -0.661 | 16.365 | 282.446 | 19944.862 | #NUM! | #NUM! | #NUM! | #NUM! | #NUM!
40.000 | -7.311 | -2.084 | 16.245 | 279.981 | 19598.675 | #NUM! | #NUM! | #NUM! | #NUM! | #NUM!
45.000 | -12.311 | -3.492 | 16.002 | 277.578 | 19264.098 | #NUM! | #NUM! | #NUM! | #NUM! | #NUM!

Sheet: Komponenten
 |  |  |  |  |  |  | Version | Version 1 |  | Version 2 |  | Version 2a
 |  |  |  |  |  |  | Challenges | 1 |  | 2 |  | -
Bezeichnung | Shop | Art.-Nr. | Anz/VPE | VPEs | Anz Ges | Preis/VPE | Gesamtpreis | Verbaut | Preis Verb. | Verbaut | Preis Verb. | Verbaut | Preis Verb.
Gewindestange M3 | Segor |  | 1 | 1 | 1 | 2.90 € | 2.90 € | 0.2 | 0.58 € | 0.2 | 0.58 € | 0.2 | 0.58 €
Gelenkbolzen M3 | Segor |  | 2 | 1 | 2 | 2.90 € | 2.90 € | 2 | 2.90 € | 2 | 2.90 € | 2 | 2.90 €
Achse 4x35 | Segor |  | 2 | 1 | 2 | 0.90 € | 0.90 € | 2 | 0.90 € | 2 | 0.90 € | 2 | 0.90 €
Kugellager MR74 | Kugellager Express | MR74ZZ | 1 | 8 | 8 | 1.07 € | 8.56 € | 4 | 4.28 € | 4 | 4.28 € | 4 | 4.28 €
Kugellager MR106 | Kugellager Express | MR106ZZ | 1 | 4 | 4 | 1.19 € | 4.76 € | 0 | 0.00 € | 2 | 2.38 € | 0 | 0.00 €
Kugellager 6800 | Kugellager Express | 6800 | 1 | 1 | 1 | 1.09 € | 1.09 € | 1 | 1.09 € | 0 | 0.00 € | 0 | 0.00 €
Kugellager 6808 | Kugellager Express | 6808ZZ | 1 | 4 | 4 | 3.69 € | 14.76 € | 4 | 14.76 € | 4 | 14.76 € | 4 | 14.76 €
Peha-Haft 4cm | Apotheke |  | 4 | 1 | 4 | 1.80 € | 1.80 € | 1 | 0.45 € | 0 | 0.00 € | 0 | 0.00 €
Peha-Haft 6cm | Apotheke |  | 4 | 1 | 4 | 2.70 € | 2.70 € | 0.5 | 0.34 € | 0 | 0.00 € | 0 | 0.00 €
Zahnrad M0,5 Z17 | Conrad | 213942 | 1 | 1 | 1 | 4.49 € | 4.49 € | 0 | 0.00 € | 0 | 0.00 € | 0 | 0.00 €
Zahnrad M0,5 Z18 | Conrad | 213950 | 1 | 1 | 1 | 4.45 € | 4.45 € | 1 | 4.45 € | 0 | 0.00 € | 0 | 0.00 €
Zahnrad M0,5 Z19 | Conrad | 213969 | 1 | 1 | 1 | 4.49 € | 4.49 € | 0 | 0.00 € | 1 | 4.49 € | 0 | 0.00 €
Zahnrad M0,5 Z23 | Conrad | 214000 | 1 | 1 | 1 | 4.95 € | 4.95 € | 0 | 0.00 € | 0 | 0.00 € | 0 | 0.00 €
Zahnrad M0,5 Z40 | Conrad | 231851 | 1 | 1 | 1 | 5.75 € | 5.75 € | 1 | 5.75 € | 0 | 0.00 € | 0 | 0.00 €
Zahnriemen T2,5 Z98 L245 | Conrad | 209521 | 1 | 1 | 1 | 5.99 € | 5.99 € | 0 | 0.00 € | 0 | 0.00 € | 1 | 5.99 €
Zahnriemenrad T2,5 Z12 | Conrad | 209510 | 1 | 1 | 1 | 5.99 € | 5.99 € | 0 | 0.00 € | 0 | 0.00 € | 1 | 5.99 €
Servo HK15138 | HobbyKing |  | 1 | 1 | 1 | 3.00 € | 3.00 € | 1 | 3.00 € | 1 | 3.00 € | 1 | 3.00 €
O-Ring 6 x 2,6 | Segor |  | 10 | 1 | 10 | 0.60 € | 0.60 € | 0 | 0.00 € | 0 | 0.00 € | 0 | 0.00 €
O-Ring 9,8 x 2,4 | Segor |  | 10 | 1 | 10 | 0.80 € | 0.80 € | 0 | 0.00 € | 0 | 0.00 € | 0 | 0.00 €
 |  |  |  |  |  | Gesamt | 80.08 € |  | 38.50 € |  | 33.29 € |  | 38.40 €

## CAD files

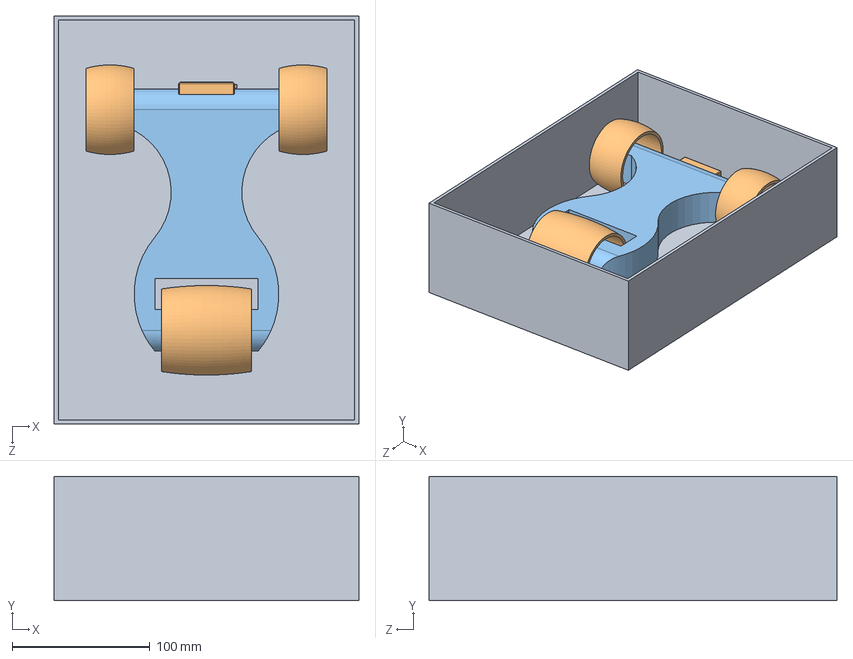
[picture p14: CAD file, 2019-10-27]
Teilnehmer/ultimate/V0 - draft/draft.SLDASM
221.0 x 90.0 x 296.0 mm
F-OR1-Normbox
draft_wheel x 3
draft_frame
Motor_B20-30-24S-FIN-Gehaeuse
Motor_B20-30-24S-FIN-FlanschHinten
Motor_B20-30-24S-FIN-FlanschVorne
Motor_B20-30-24S-FIN-Rotorwelle
Motor_B20-30-24S-FIN-Lager x 2
Motor_B20-30-24S-FIN-Masse
Servo HK15138
Rhino Lipoly Pack 1050
Turnigy Motorregler

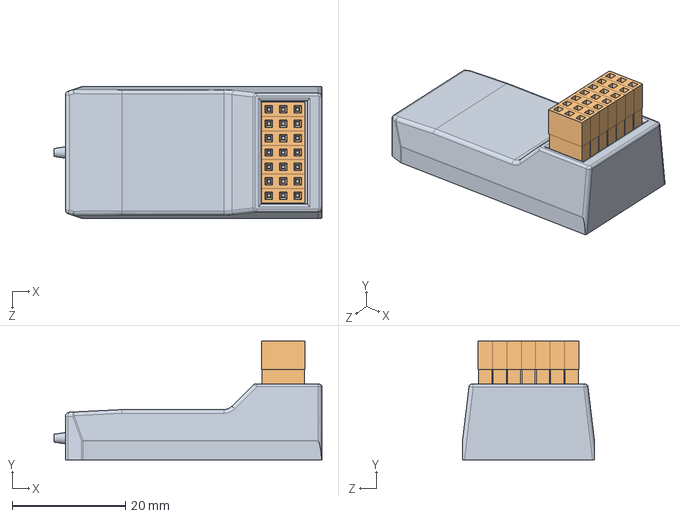
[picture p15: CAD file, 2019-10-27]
Komponenten/Hobby King TR6A Empfänger.SLDASM
47.3 x 21.0 x 23.3 mm
Hobby King TR6A Empfänger
Stecker-3pol x 7

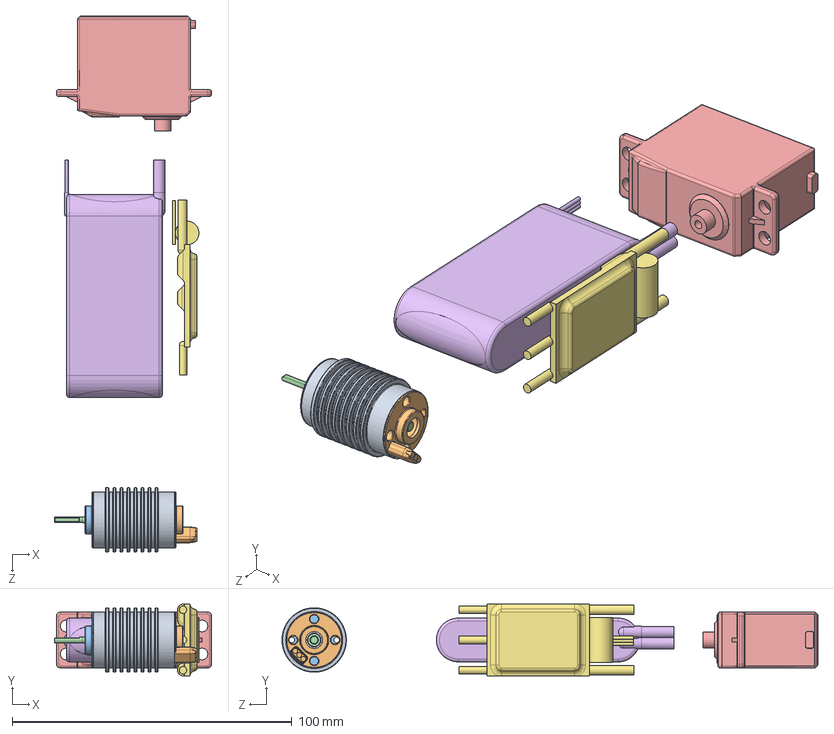
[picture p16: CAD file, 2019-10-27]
Teilnehmer/ultimate/V0 - draft/draft_components.SLDASM
56.3 x 25.6 x 191.5 mm
Motor_B20-30-24S-FIN-Gehaeuse
Motor_B20-30-24S-FIN-FlanschHinten
Motor_B20-30-24S-FIN-FlanschVorne
Motor_B20-30-24S-FIN-Rotorwelle
Servo HK15138
Rhino Lipoly Pack 1050
Turnigy Motorregler

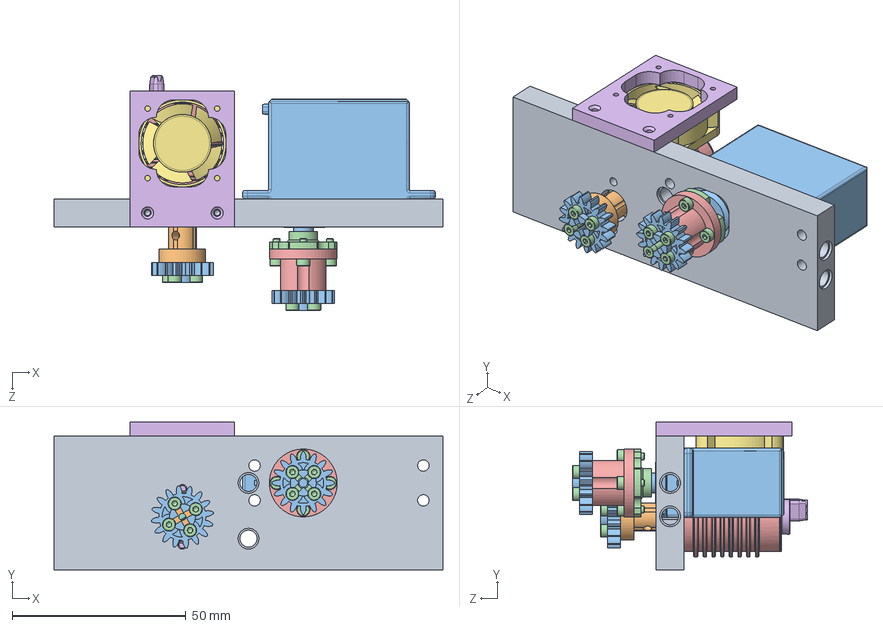
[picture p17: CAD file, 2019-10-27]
Teilnehmer/ultimate/V2 - Lego/Antriebseinheit.SLDASM
111.8 x 42.4 x 67.6 mm
Aufnahme-Motoren
Adapter-Motor-Zahnrad-16Z
Lego Zahnrad 16Z x 2
DIN 912 M2 x 6 --- 6N x 12
Motor_B20-30-24S-FIN-Gehaeuse
Motor_B20-30-24S-FIN-FlanschHinten
Motor_B20-30-24S-FIN-FlanschVorne
Motor_B20-30-24S-FIN-Rotorwelle
Motor_B20-30-24S-FIN-Lager x 2
Motor_B20-30-24S-FIN-Masse
Servo HK15138
Servo-Horn-4er-modifiziert
Adapter-Servo-Zahnrad-16Z
Aufnahme-Lüfter
Hobby King X-Car 60A Brushless Car ESC - Lüfter

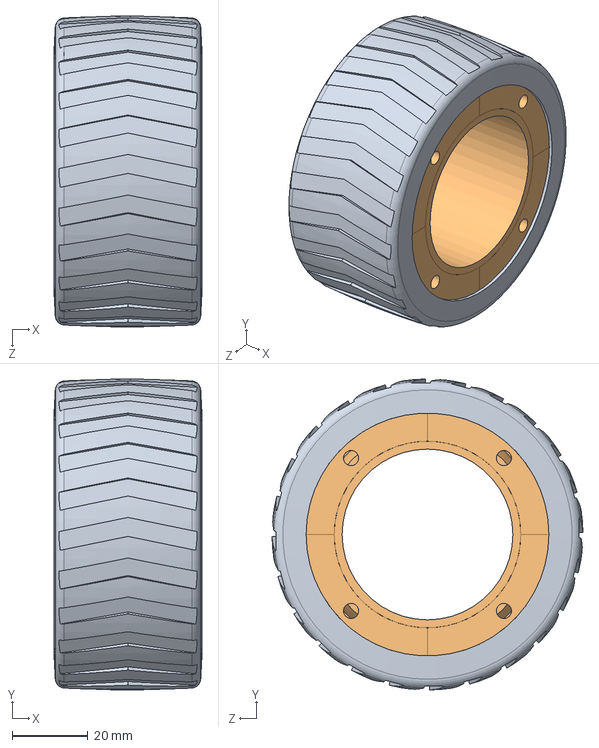
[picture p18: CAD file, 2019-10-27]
Teilnehmer/ultimate/V1 - 3Wheeler/Reifen-Vorne-Gussform.SLDASM
39.0 x 82.0 x 82.0 mm
Reifen-Vorne-Gussform x 5

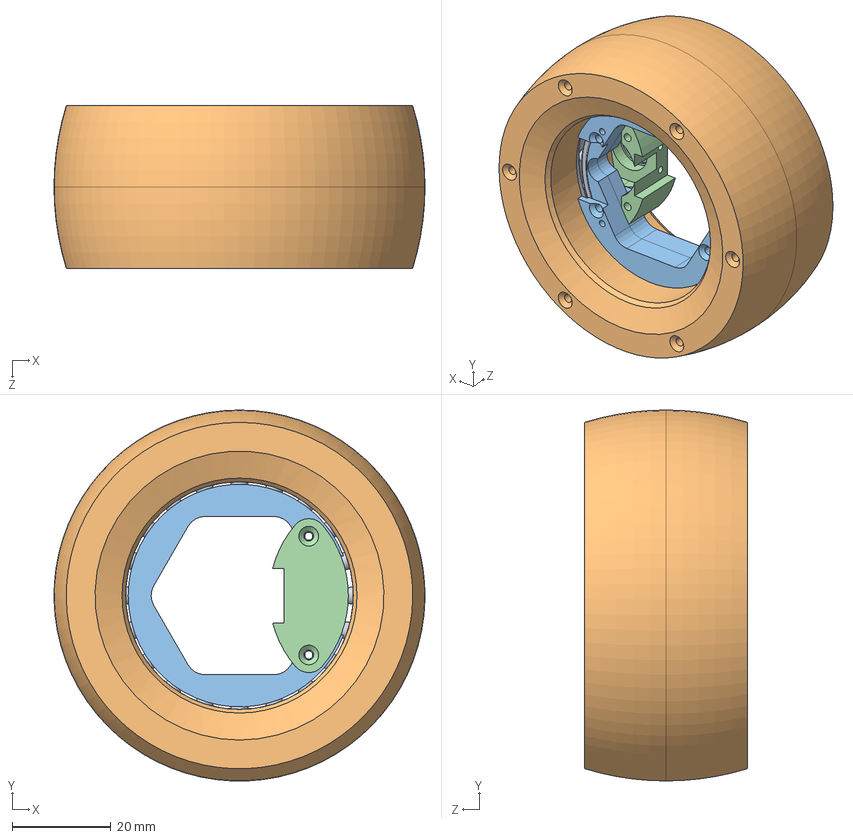
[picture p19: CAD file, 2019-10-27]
Teilnehmer/ultimate/V3 - 4Wheeler/Rad.SLDASM
75.0 x 75.0 x 33.0 mm
Kugellager - 61808 6808
Rad-Korpus x 2
Rad-Nabe x 2
Rad-Adapter

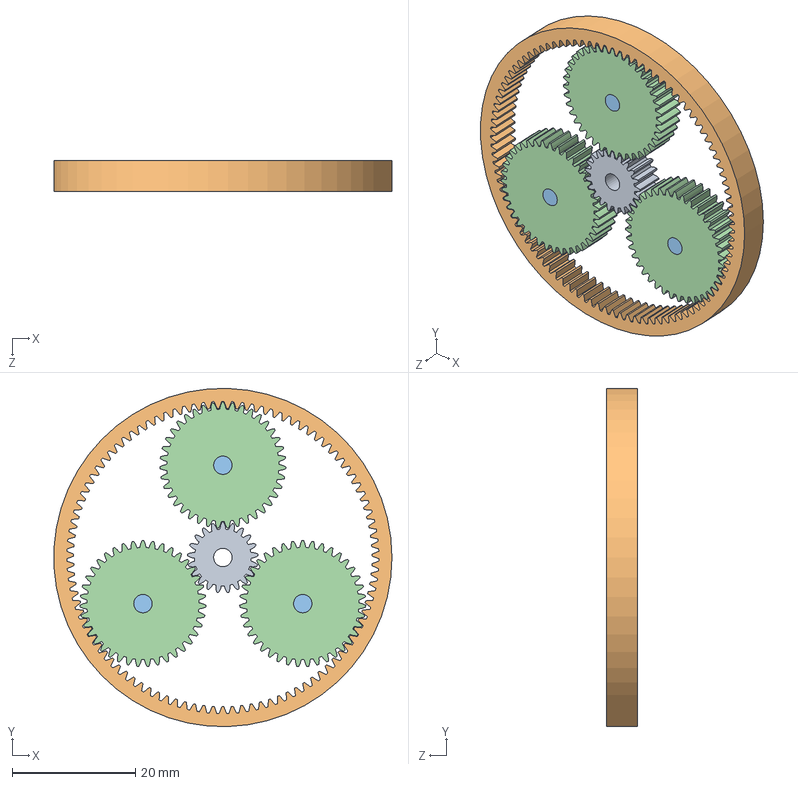
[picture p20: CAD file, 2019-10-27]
Teilnehmer/ultimate/Test/Planetengetriebe.SLDASM
55.0 x 55.0 x 5.00 mm
Planetengetriebe Sonnenrad 0.5M
Planetengetriebe Hohlrad 0.5M
Planetengetriebe Steg
Planetengetriebe Planetenrad 0.5M x 3

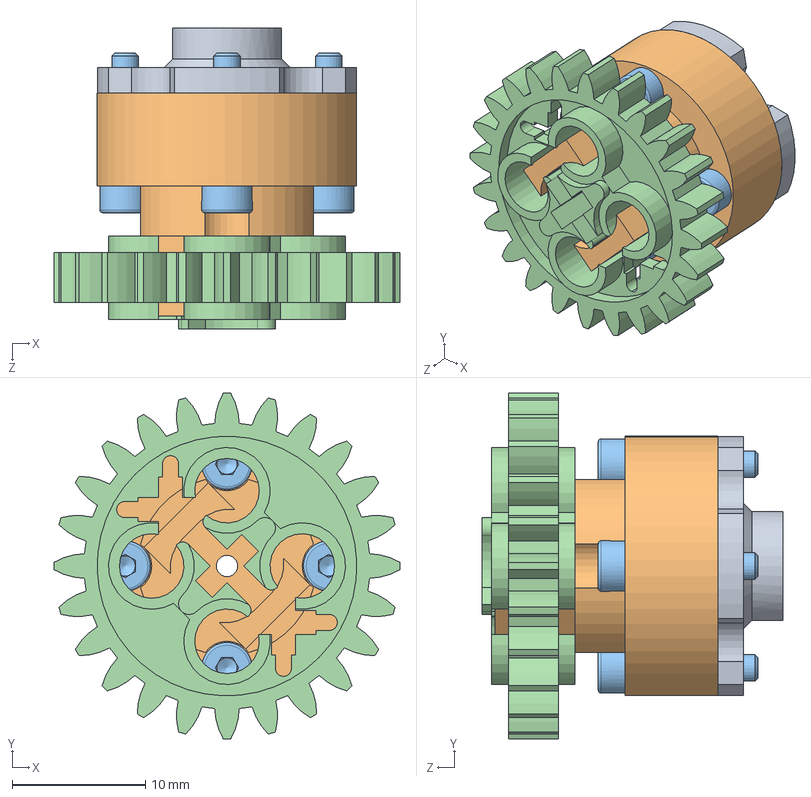
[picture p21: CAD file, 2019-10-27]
Teilnehmer/ultimate/V2 - Lego/Adapter-Servo-Zahnrad-24Z.SLDASM
26.0 x 26.0 x 22.6 mm
Servo-Horn-4er-modifiziert
Adapter-Servo-Zahnrad-24Z
DIN 912 M2 x 10 --- 10N x 4
Lego Zahnrad 24Z

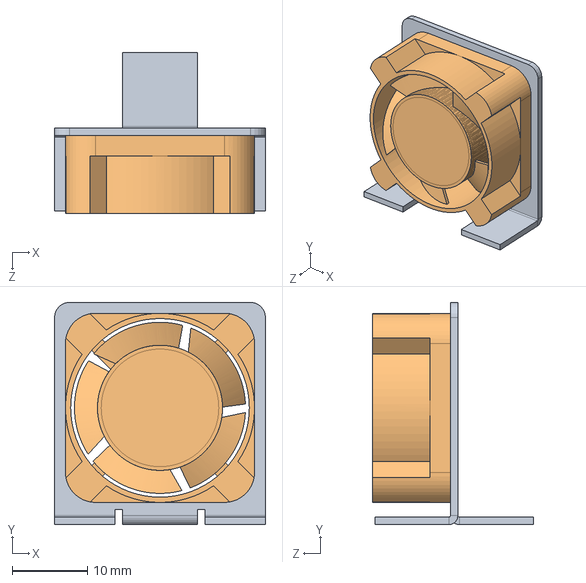
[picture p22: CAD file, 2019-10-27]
Teilnehmer/ultimate/V3 - 4Wheeler/Halterung-Lüfter.SLDASM
28.0 x 29.5 x 21.3 mm
Halterung-Lüfter
Hobby King X-Car 60A Brushless Car ESC - Lüfter

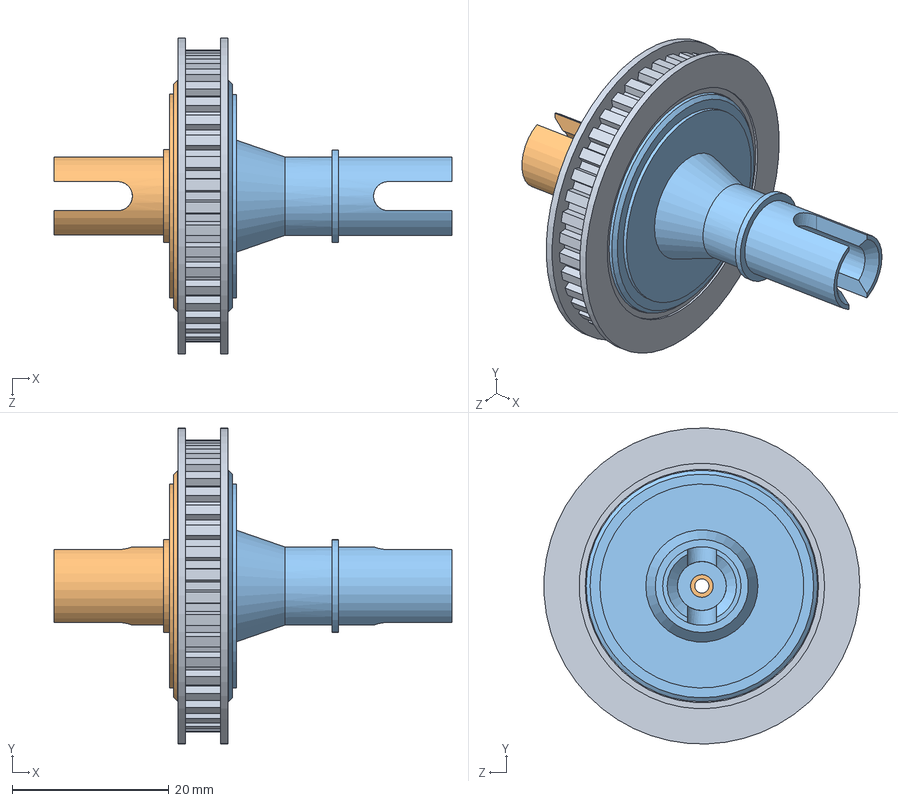
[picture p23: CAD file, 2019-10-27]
Komponenten/Kugel-Diff Hobbyking Mission-D.SLDASM
50.8 x 40.3 x 40.3 mm
Kugel-Diff Hobbyking Mission-D Riemenrad
Kugel-Diff Hobbyking Mission-D Achse1
Kugel-Diff Hobbyking Mission-D Achse2
Kugel-Diff Hobbyking Mission-D Laufscheibe x 2

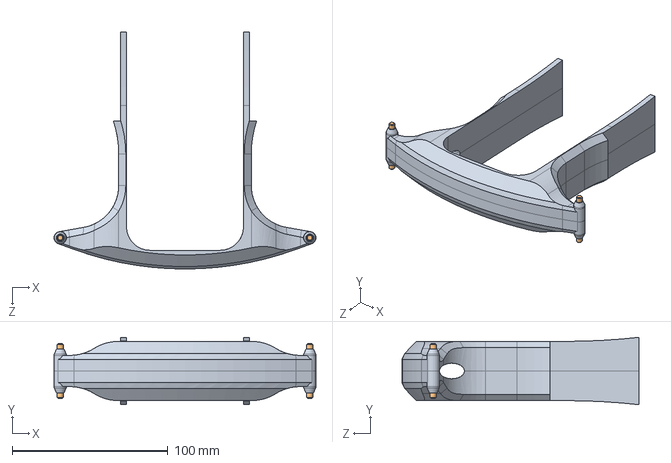
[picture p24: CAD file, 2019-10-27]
Teilnehmer/ultimate/V1 - 3Wheeler/Rahmen-Vorne.SLDASM
168.0 x 43.2 x 152.0 mm
Rahmen-Vorne x 2
Achse 4mm x 2

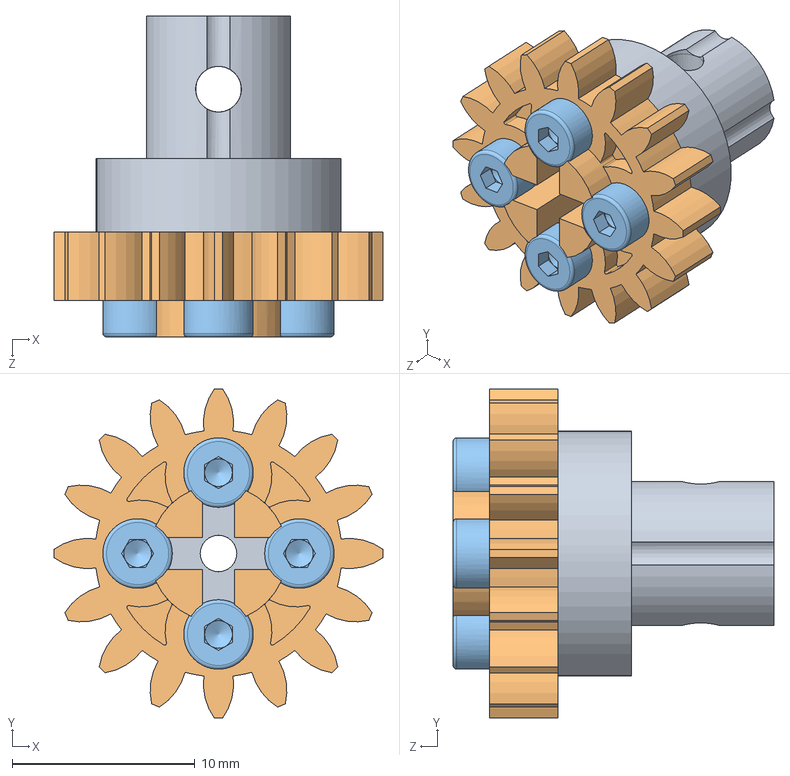
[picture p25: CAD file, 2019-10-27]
Teilnehmer/ultimate/V2 - Lego/Adapter-Motor-Zahnrad-16Z.SLDASM
18.0 x 18.0 x 17.5 mm
Adapter-Motor-Zahnrad-16Z
Lego Zahnrad 16Z
DIN 912 M2 x 6 --- 6N x 4

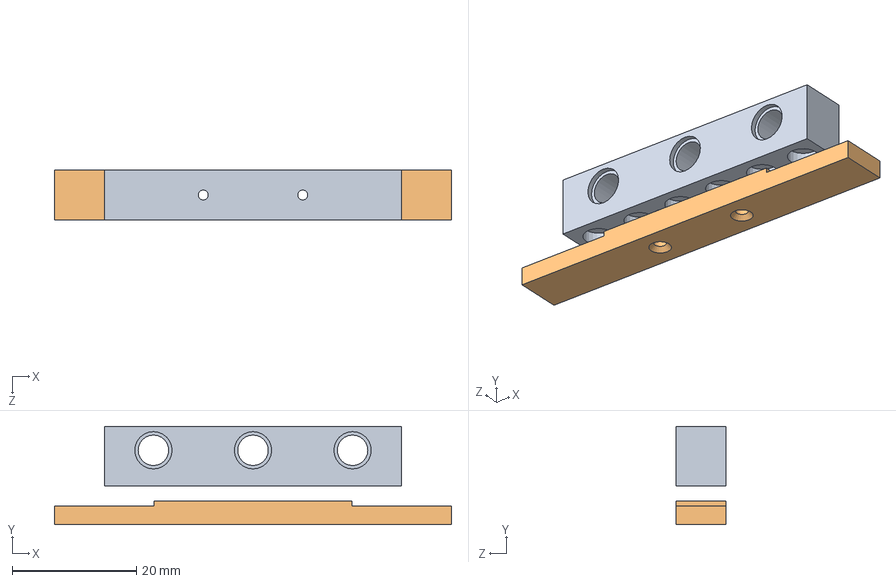
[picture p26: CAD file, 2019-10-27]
Teilnehmer/ultimate/V2 - Lego/Fixierung.SLDASM
63.8 x 15.8 x 8.00 mm
Gewinde-Block
Fixier-Block

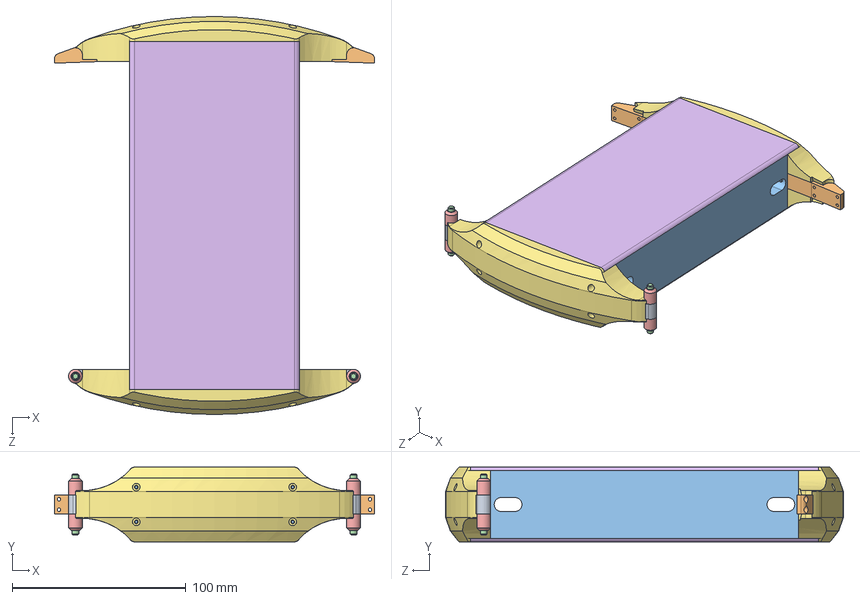
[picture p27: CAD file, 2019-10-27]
Teilnehmer/ultimate/V3 - 4Wheeler/Rahmen.SLDASM
184.1 x 43.0 x 229.0 mm
Rahmen-Vorne
Rahmen-Hinten
Rahmen-Seite x 2
Achse 4mm x 2
Rad-Abstandshalter x 4
Rahmen-Deckel x 2
Rahmen-Verkleidung x 2

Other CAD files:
Teilnehmer/ultimate/leer.SLDASM
Teilnehmer/ultimate/V1 - 3Wheeler/Antrieb.SLDASM
Teilnehmer/ultimate/V1 - 3Wheeler/Fertigung/Rahmen-Antrieb-Flach.SLDASM
Teilnehmer/ultimate/V2 - Lego/Adapter-Servo-Zahnrad-16Z.SLDASM
Komponenten/F-OR1-Normbox.SLDPRT
Komponenten/Hobby King GT-2 Empfänger.SLDPRT
Komponenten/Hobby King TR6A Empfänger.SLDPRT
Komponenten/Hobby King X-Car 60A Brushless Car ESC - Kondensator.SLDPRT
Komponenten/Hobby King X-Car 60A Brushless Car ESC - Lüfter.SLDPRT
Komponenten/Hobby King X-Car 60A Brushless Car ESC - Schalter.SLDPRT
Komponenten/Hobby King X-Car 60A Brushless Car ESC.SLDASM
Komponenten/Hobby King X-Car 60A Brushless Car ESC.SLDPRT
Komponenten/Kugel-Diff Hobbyking Mission-D Achse1.SLDPRT
Komponenten/Kugel-Diff Hobbyking Mission-D Achse2.SLDPRT
Komponenten/Kugel-Diff Hobbyking Mission-D Laufscheibe.SLDPRT
Komponenten/Kugel-Diff Hobbyking Mission-D Riemenrad.SLDPRT
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

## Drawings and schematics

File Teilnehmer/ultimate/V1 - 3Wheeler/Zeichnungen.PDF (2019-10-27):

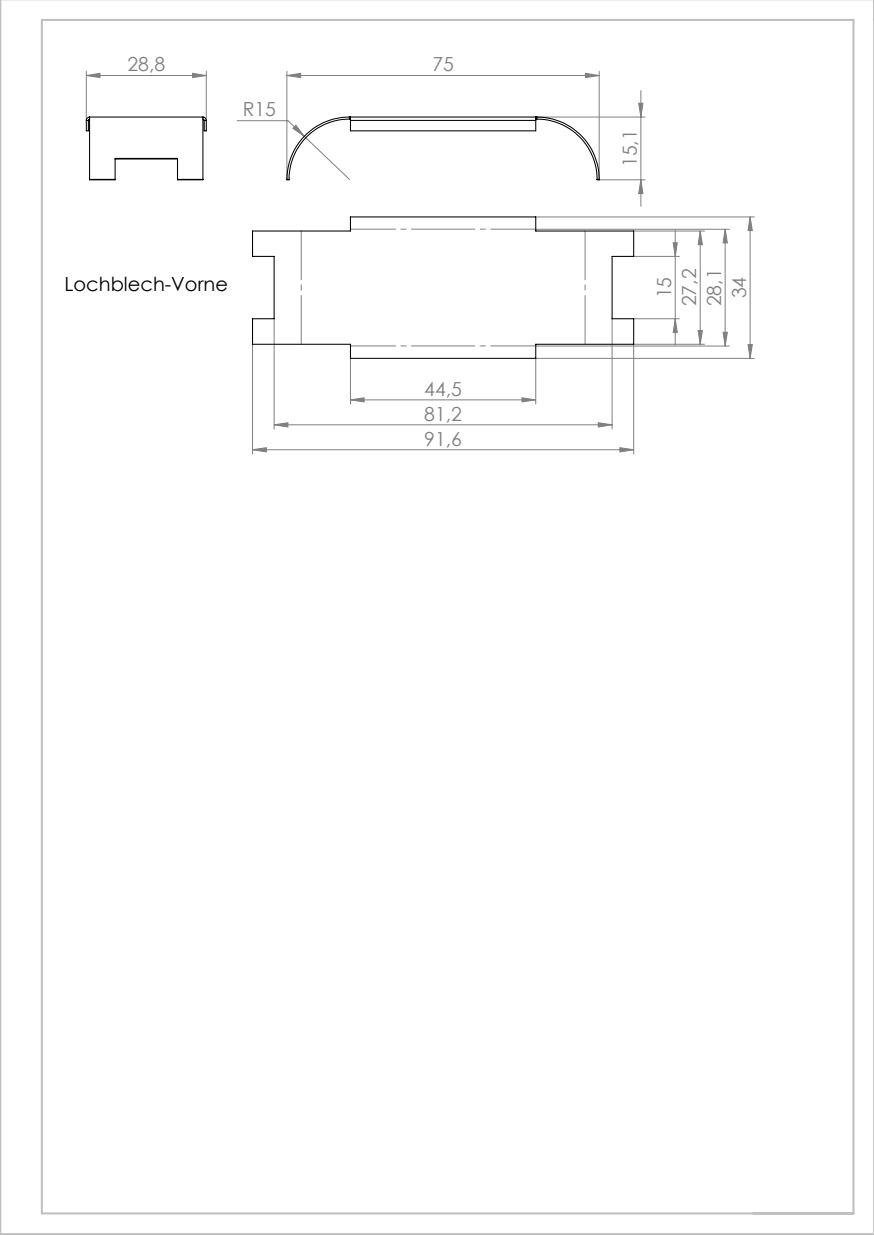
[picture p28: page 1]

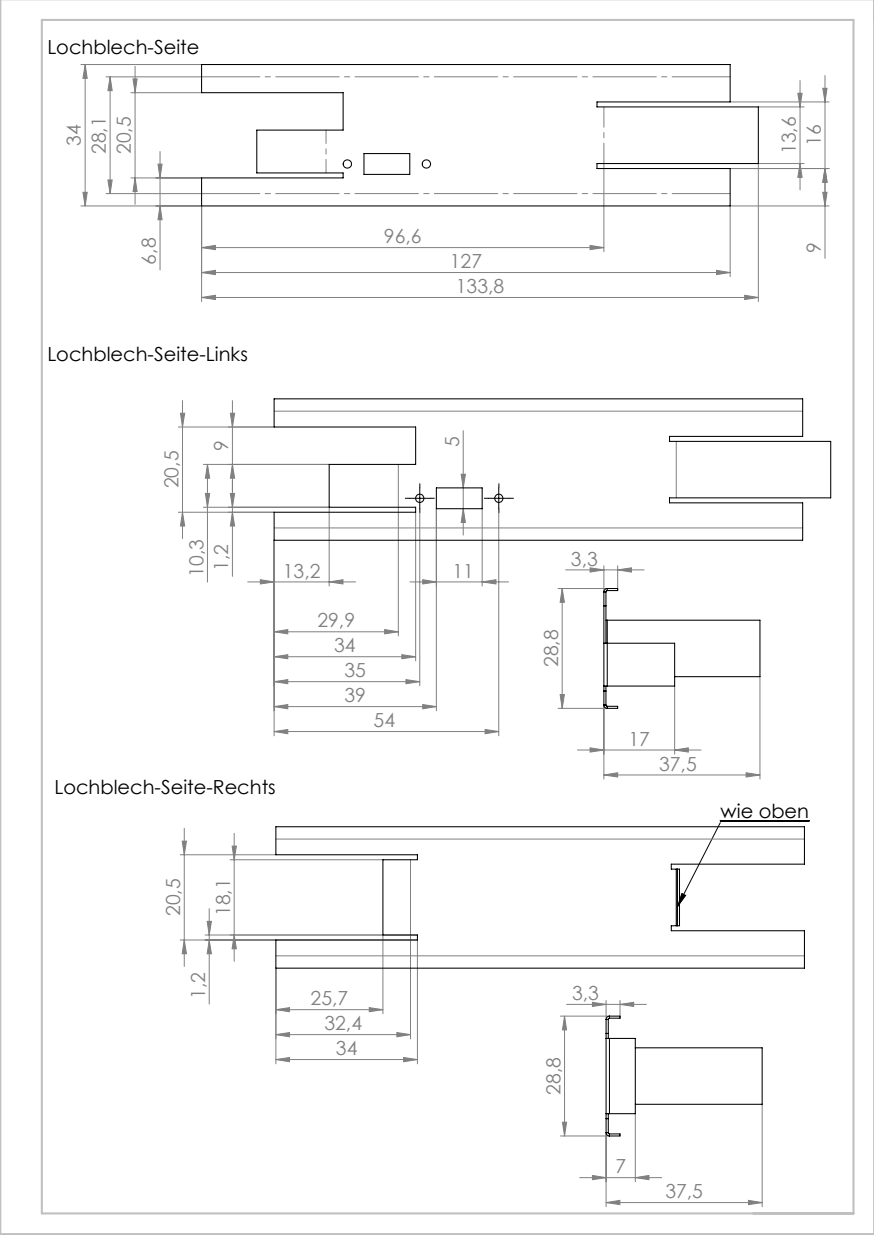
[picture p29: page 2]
wie oben

Lochblech-Seite-Links

Lochblech-Seite-Rechts

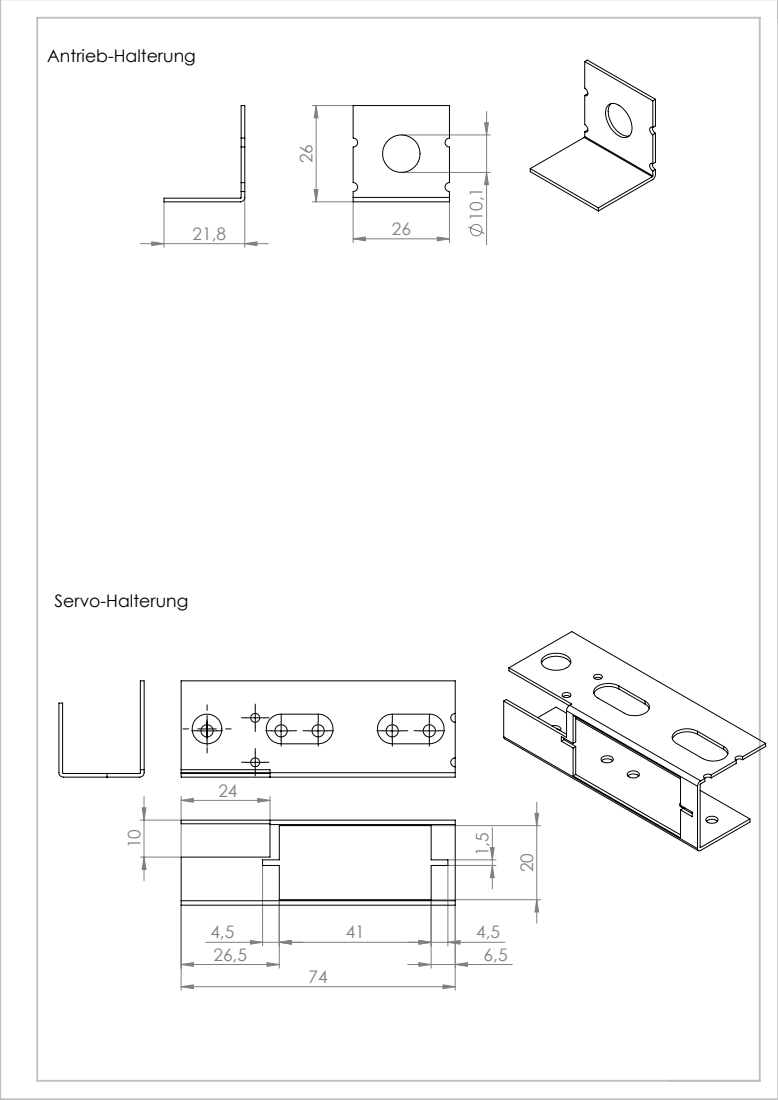
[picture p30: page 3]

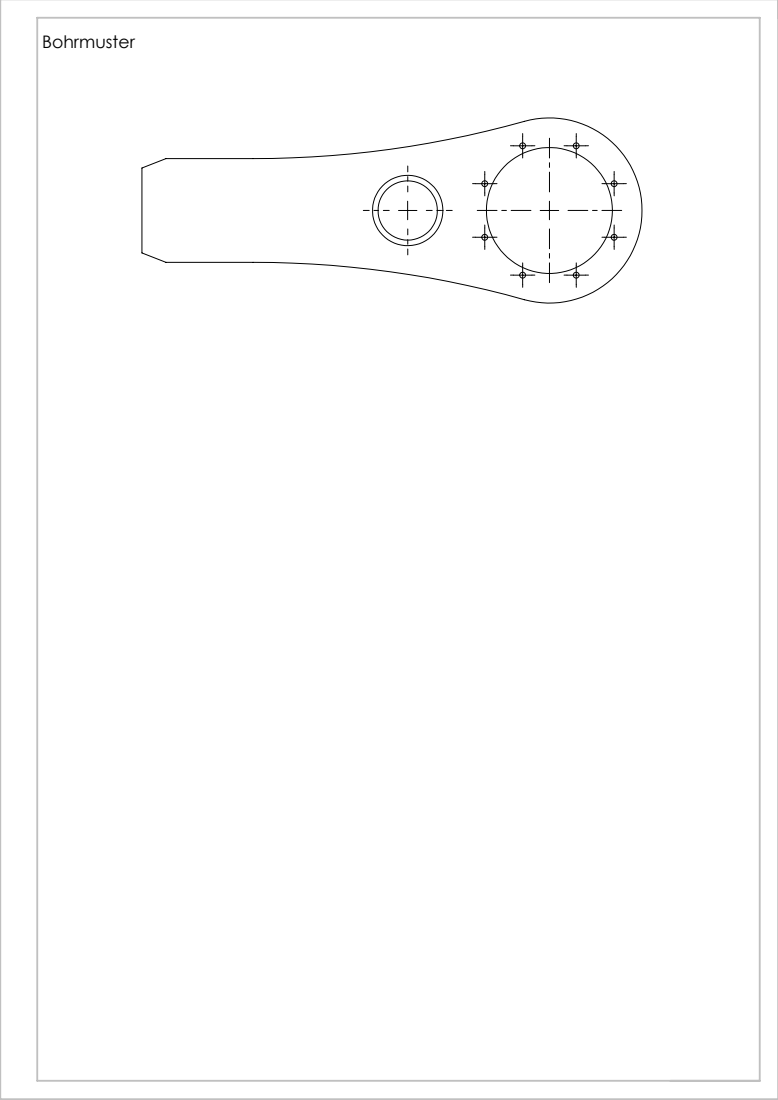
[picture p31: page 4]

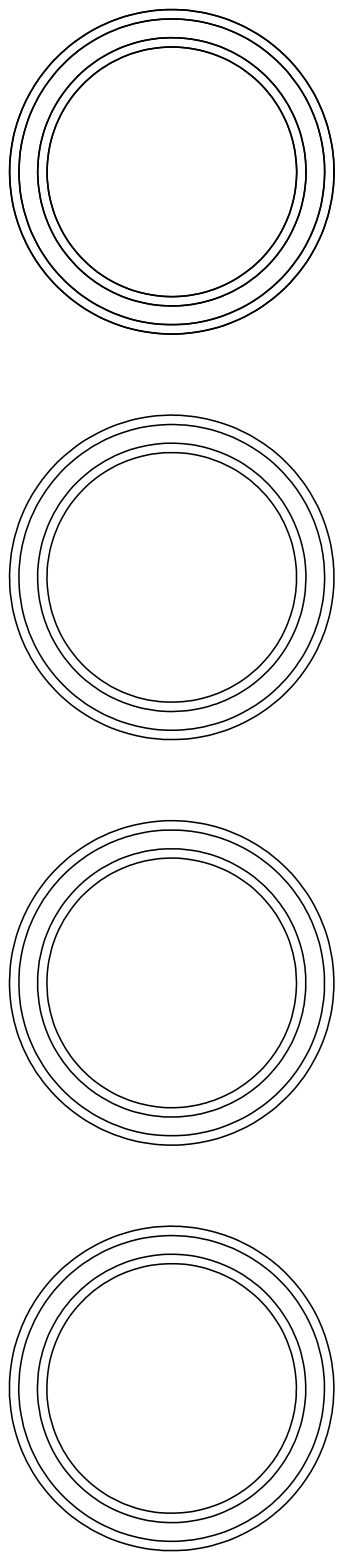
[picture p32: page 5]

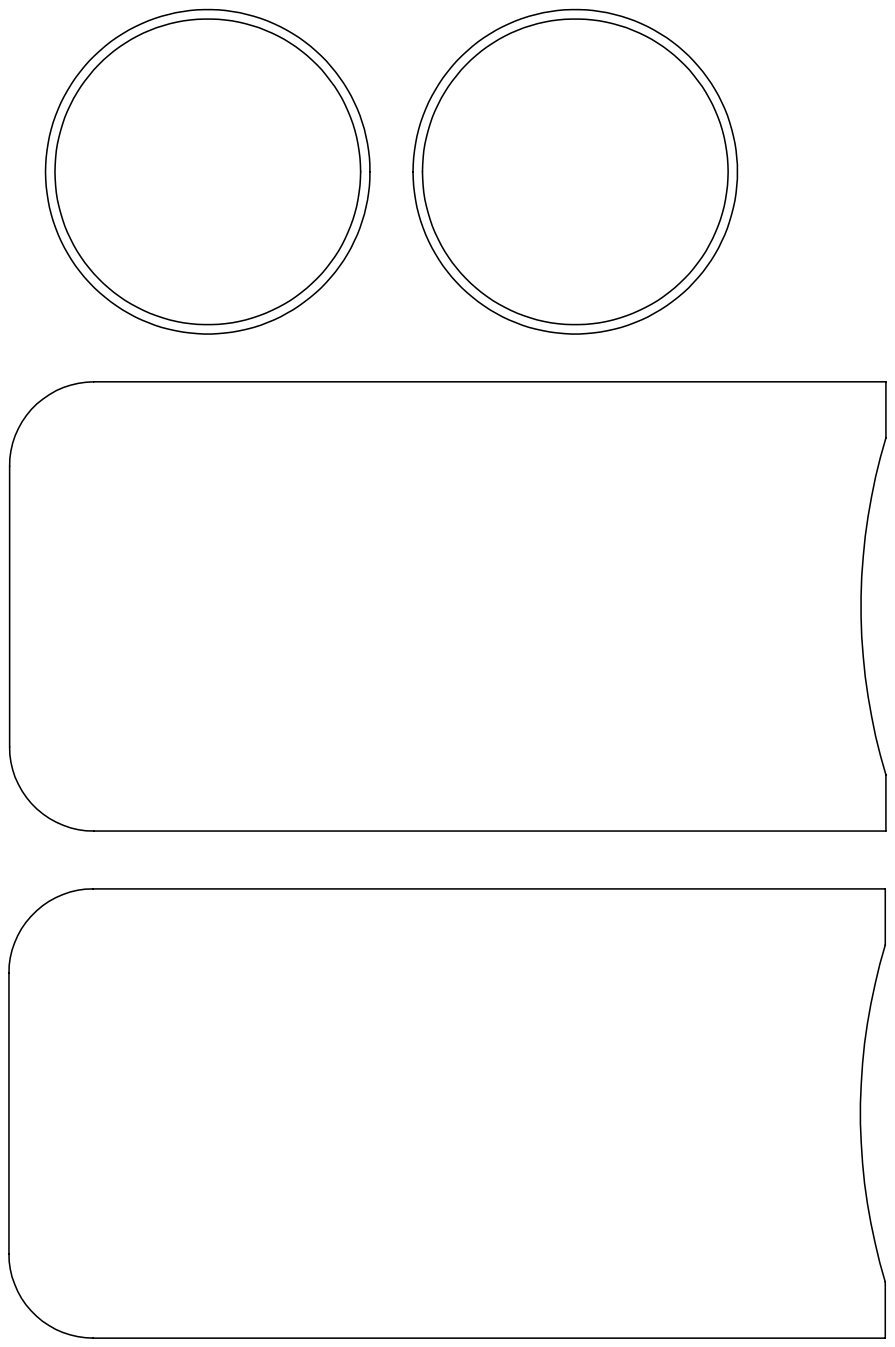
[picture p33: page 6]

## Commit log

2014-05-16 CAD-Daten hinzugefügt
    [Akku_Rhino1050.stp, Empfaenger_GT2.stp, Empfaenger_TR6A.stp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]
2014-06-03 Neuen Motorregler hinzugefügt (Modellierung Teil 1)
    [Hobby King X-Car Brushless Car ESC.SLDPRT]
2014-06-03 Kühler hinzugefügt
    [Hobby King X-Car 60A Brushless Car ESC.SLDPRT, Hobby King X-Car Brushless Car ESC.SLDPRT]
2014-06-03 Lüfter ergänzt
    [Hobby King X-Car 60A Brushless Car ESC.SLDPRT]
2014-06-04 Lüfter separiert, Modellierung Regler abgeschlossen
    [Hobby King X-Car 60A Brushless Car ESC - Lüfter.SLDPRT, Hobby King X-Car 60A Brushless Car ESC.SLDASM, Hobby King X-Car 60A Brushless Car ESC.SLDPRT]
2014-06-04 Schalter für Regler hinzugefügt
    [Hobby King X-Car 60A Brushless Car ESC - Lüfter.SLDPRT, Hobby King X-Car 60A Brushless Car ESC - Schalter.SLDPRT, Hobby King X-Car 60A Brushless Car ESC.SLDASM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]
2014-06-04 Kondensator für Motorregler hinzugefügt
    [Hobby King X-Car 60A Brushless Car ESC - Kondensator.SLDPRT]
2014-06-05 Datenblatt für Motorregler hinzugefügt
2014-06-05 Neuen Motorregler eingearbeitet
2014-06-05 Step für Motorregler hinzugefügt
    [Hobby King X-Car 60A Brushless Car ESC - Kondensator.STEP, Hobby King X-Car 60A Brushless Car ESC - Schalter.STEP, Hobby King X-Car 60A Brushless Car ESC.STEP]
2014-06-05 Neuer Motorregler hinzugefügt + Link auf CAD-Daten
2014-07-16 Anderweitige Verwendung des Lüfters vom Motorregler freigegeben
2014-09-02 Punktzahl für die Gesamtwertung korrigiert: (n-1)=2 bei n=3 ;-)
2015-01-06 Servo-Horn modelliert
    [Servo-Horn.SLDPRT]
2015-01-06 Fehler korrigiert
    [Servo-Horn.SLDPRT]
2019-10-27 import from svn
    [Achse 4mm.SLDPRT, Adapter-Motor-Zahnrad-16Z.SLDASM, Adapter-Motor-Zahnrad-16Z.SLDPRT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]
2020-09-06 Export 4-Wheeler
    [4-Wheeler - Antrieb-1 Antrieb-Achse-Lagerhülse-1.STL, 4-Wheeler - Antrieb-1 Antrieb-Achse-Lagerhülse-2.STL, 4-Wheeler - Antrieb-1 Antrieb-Lagerbock-1.STL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]
